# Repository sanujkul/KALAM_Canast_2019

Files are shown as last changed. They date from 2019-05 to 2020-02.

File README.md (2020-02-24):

# KALAM_Canast_2019    
These codes/files were written/developed for the Cansat competition 2019, USA.    

This folder have two types of files:  
1. Codes (.c, .c++, .ino)    
2. PCB designs    
  
Cansat 2019 was divided ino two parts: A payload and a container. Cansat is launched to the height of 750m and at the height of 450m, during descent journey,container would release the payload which will descent via auto-gyro mechanism.    
Cansat has to perform telemetry throughout its journey.   
  
Files descriptions:  
a. TeensyPayloadCodes : Have the Cansat's payload codes.   
b. Container_Final : Have the Cansat's container codes.    
c. Camera Stabilization Codes: Payload was divided into 2 subparts, minor subpart was camra stabilization system and these are codes for stabilizing the camera to shoot in a particular direction.   
d. Camera_Stabilisation_Tests: Codes written for testing Camera stabilization system.  
e. Bluetooth Tests: Camera stabilization setup used to communicate to main microcontroller (Teensy) via bluetooth and these are test codes for that.   
f. SumiranPCB: Contains PCB designs (Eagle Cad files) for the cansat.  
g. Packets: This is a class developed to use telemetry packet as an object to ease or work in organising the codeflow.

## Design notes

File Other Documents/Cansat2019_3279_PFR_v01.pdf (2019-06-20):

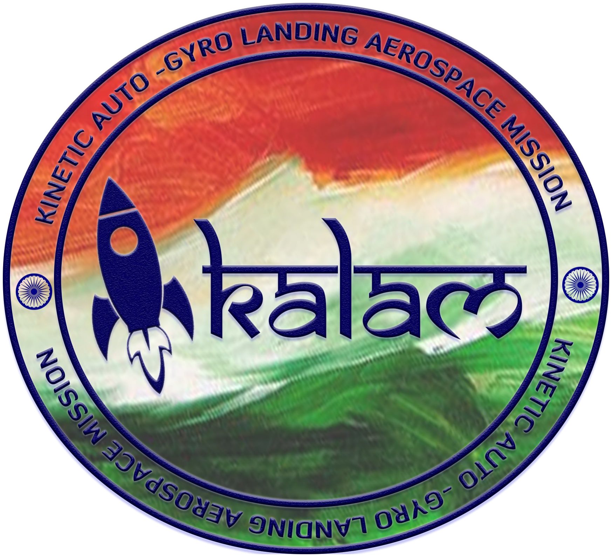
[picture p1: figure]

# Netaji Subhas University of Technology CanSat 2019 Post Flight Review (PFR)

#3279

K.A.L.A.M.

## Kinetic Autogyro Landing Aerospace Mission

CanSat 2019 PFR: Team 3279 (Team KALAM)

# Introduction

## ISHITA KOCHAR

CanSat 2019 PFR: Team 3279 (Team KALAM)

## Presentation Outline

S. no. | SECTION | PRESENTER | SLIDE NUMBER
1. | Introduction | Ishita Kochar | 2-4
2. | Systems Overview | Arham Jain | 5-11
3. Concept of operations and | sequence of events | Sumiran Bhasin | 12-19
4. | Flight data analysis | Vineet Khurana | 20-32
5. | Failure analysis | Sanuj Kulshrestha | 33-36
6. | Lessons learned | Anmol Gulati | 37-40
Presenter: Ishita Kochar | CanSat 2019 PFR: Team 3279 (Team KALAM)

## Team Organization

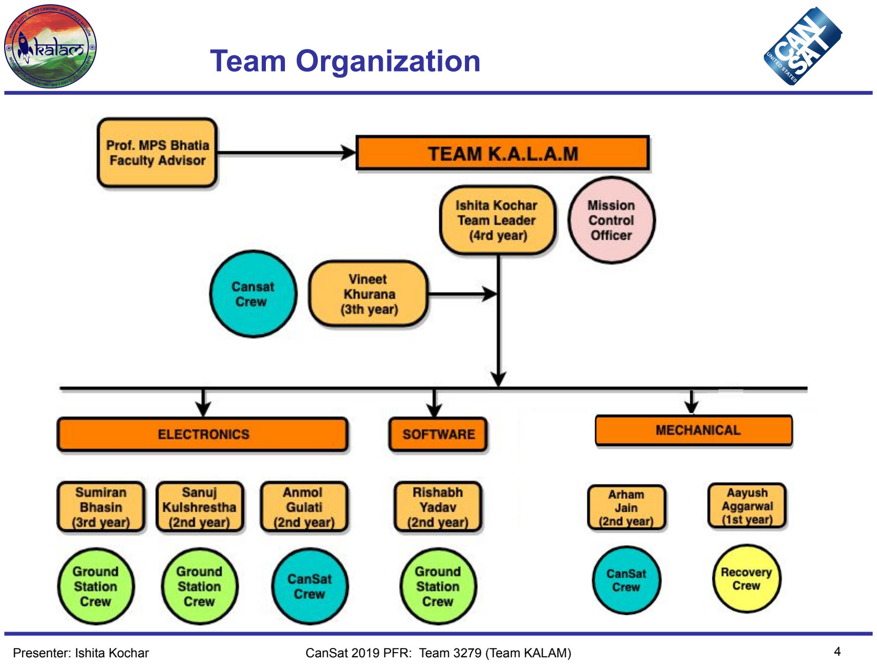
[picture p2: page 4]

Presenter: Ishita Kochar | CanSat 2019 PFR: Team 3279 (Team KALAM)

# Systems Overview

## ARHAM JAIN

CanSat 2019 PFR: Team 3279 (Team KALAM) | 5

## Payload Design Description

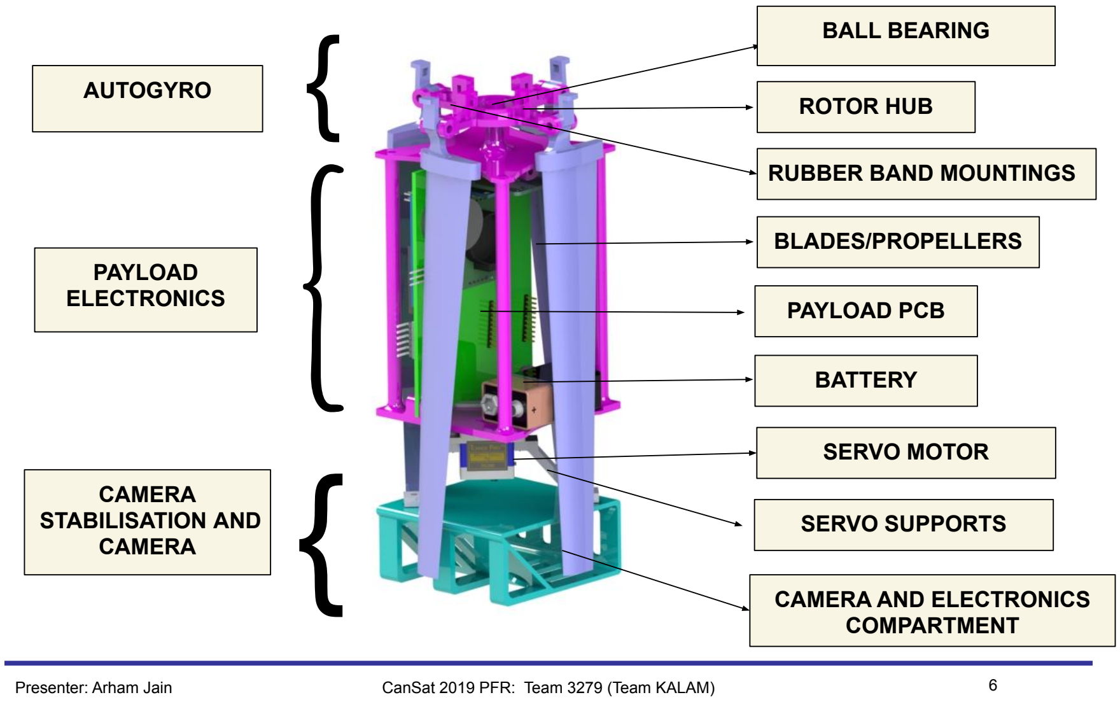
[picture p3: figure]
ROTOR HUB; BALL BEARING; BLADES/PROPELLERS; CAMERA AND ELECTRONICS COMPARTMENT; BATTERY; PAYLOAD PCB; SERVO MOTOR; SERVO SUPPORTS; RUBBER BAND MOUNTINGS; PAYLOAD ELECTRONICS; AUTOGYRO; CAMERA STABILISATION AND CAMERA; CanSat 2019 PFR: Team 3279 (Team KALAM); Presenter: Arham Jain

## Payload Design Description

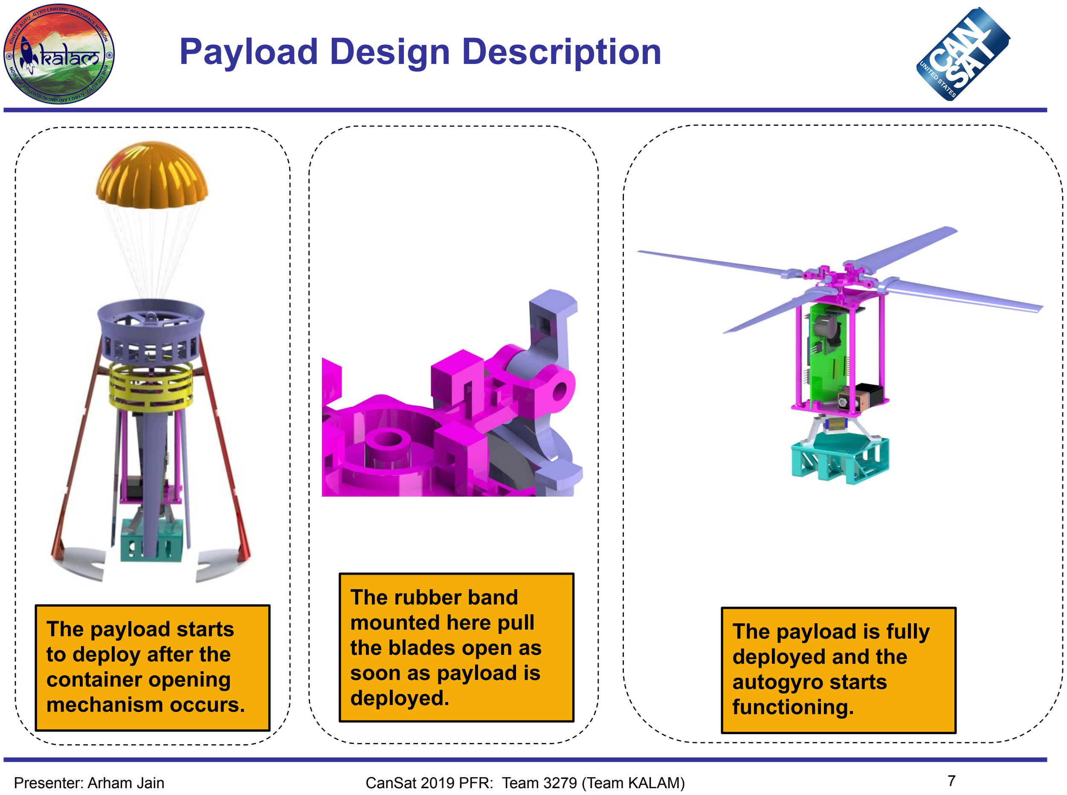
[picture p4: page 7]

Presenter: Arham Jain | CanSat 2019 PFR: Team 3279 (Team KALAM) | 7

The payload starts
to deploy after the
container opening
mechanism occurs.

The rubber band
mounted here pull
the blades open as
soon as payload is
deployed.

The payload is fully
deployed and the
autogyro starts
functioning.

## Payload Design Description

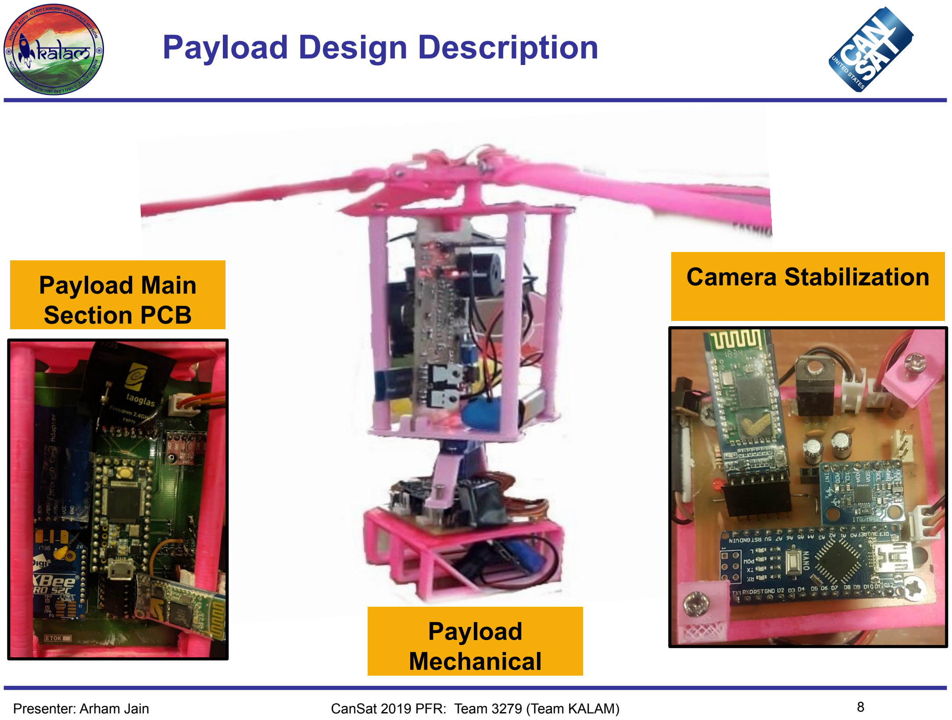
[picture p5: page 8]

Presenter: Arham Jain | CanSat 2019 PFR: Team 3279 (Team KALAM) | 8

Payload Main
Section PCB

Camera Stabilization

Payload
Mechanical

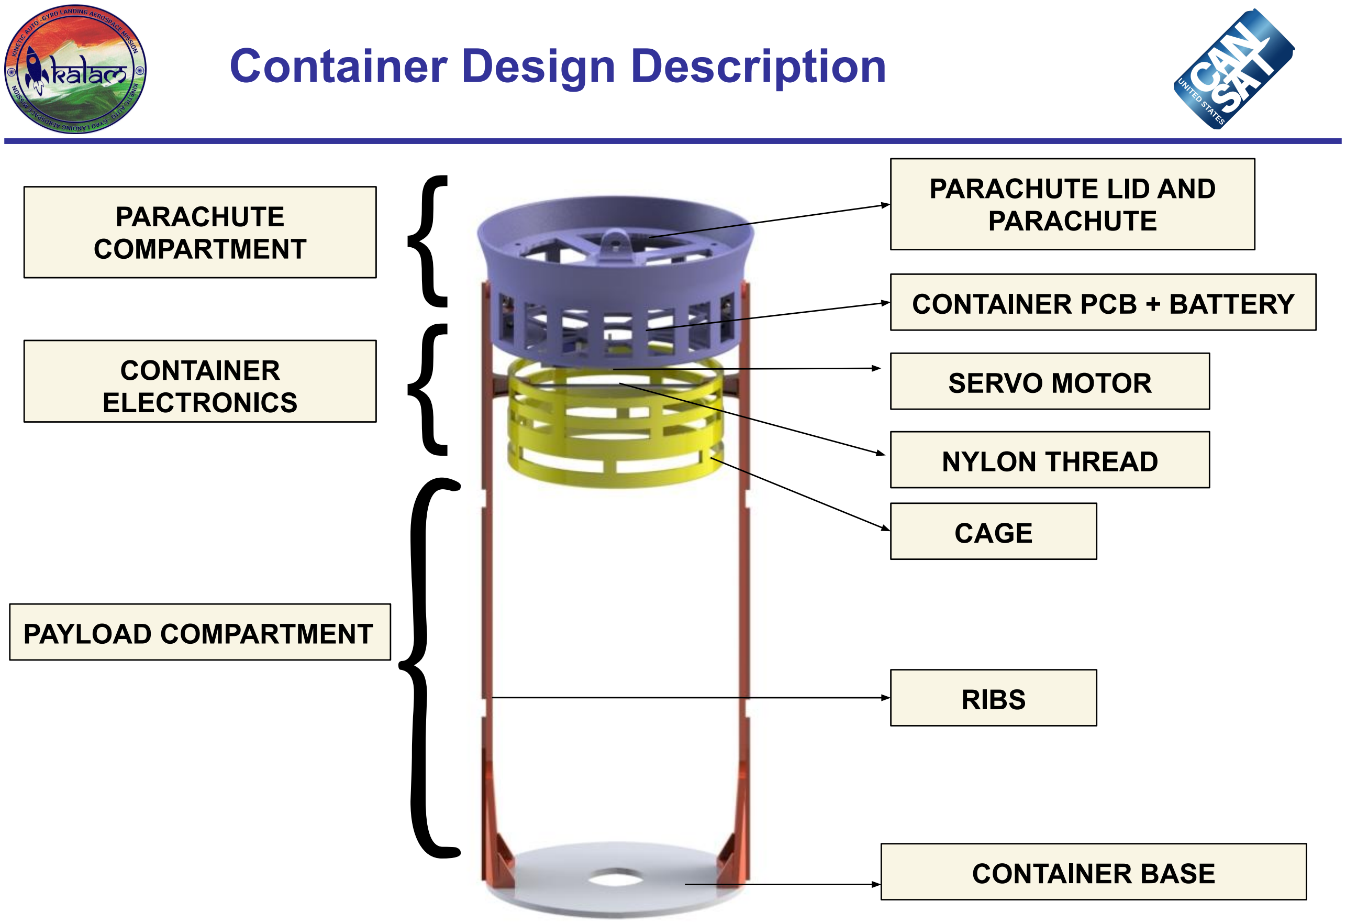
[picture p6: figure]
Container Design Description; CAGE; RIBS; CONTAINER PCB + BATTERY; SERVO MOTOR; CONTAINER BASE; NYLON THREAD; PARACHUTE COMPARTMENT; CONTAINER ELECTRONICS; PAYLOAD COMPARTMENT; PARACHUTE LID AND PARACHUTE

CanSat 2019 PFR: Team 3279 (Team KALAM) Presenter: Arham Jain

## Container Design Description

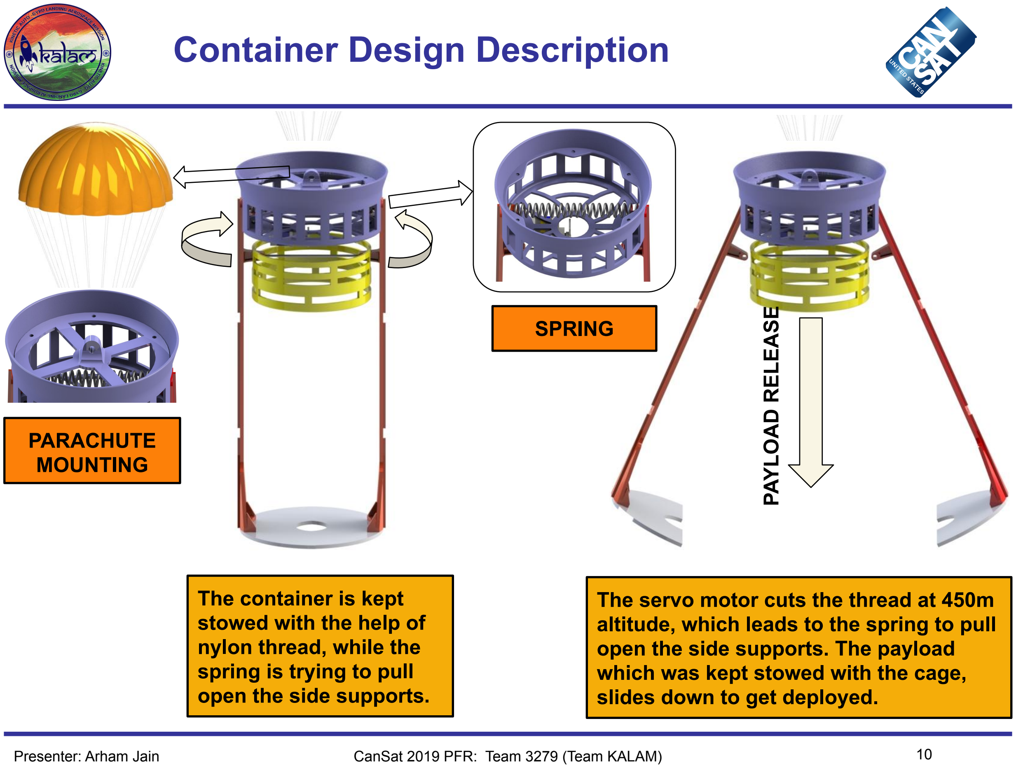
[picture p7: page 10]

CanSat 2019 PFR: Team 3279 (Team KALAM) | 10

The container is kept
stowed with the help of
nylon thread, while the
spring is trying to pull
open the side supports.

The servo motor cuts the thread at 450m altitude, which leads to the spring to pull open the side supports. The payload which was kept stowed with the cage, slides down to get deployed.

Presenter: Arham Jain

SPRING

PAYLOAD RELEASE

PARACHUTE
MOUNTING

## Container Design Description

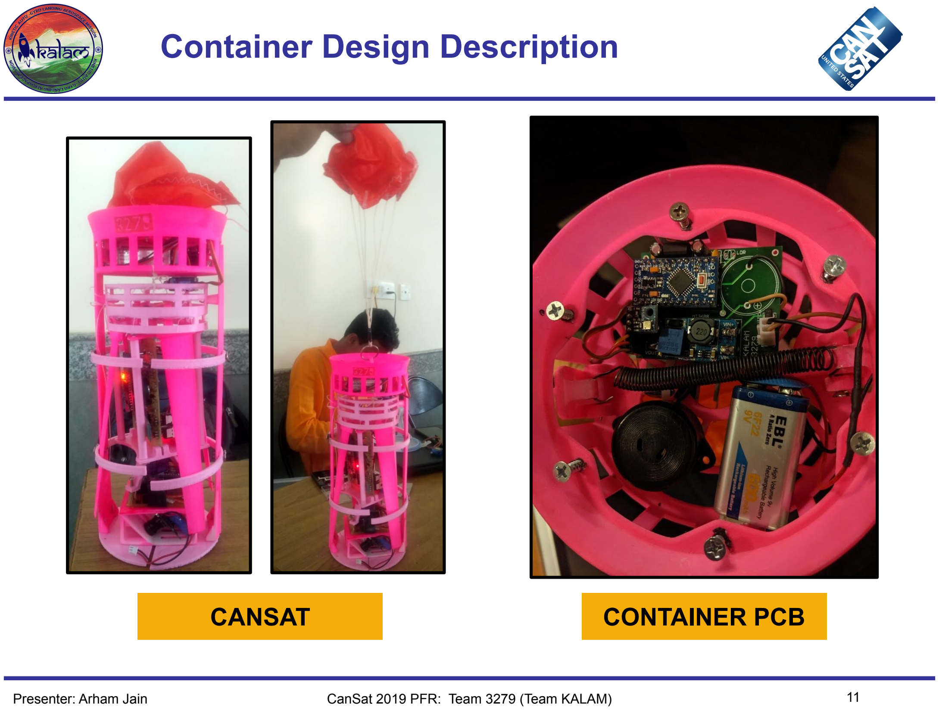
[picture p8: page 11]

Presenter: Arham Jain | CanSat 2019 PFR: Team 3279 (Team KALAM) | 11
CANSAT | CONTAINER PCB

# Concept of Operations and Sequence of Events

# Sumiran Bhasin

CanSat 2019 PFR: Team 3279 (Team KALAM)

## Comparison of planned and actual Con-Ops (1/2)

Presenter: Sumiran Bhasin

Planned Con-OPS | Actual Con-Ops | Team’s Remarks
- Payload integrity and Mechanical system integrity checks | Achieved | -
- Communication and GCS checks . | Achieved | -
- The software will be checked. | Achieved | -
- CanSat is switched ON, and telemetry starts. | Achieved | -
- CanSat integrated in the launch rocket. | Achieved | -
- CanSat released at apex at an altitude of around 700m. | Achieved | -
- Sensors start to collect data | Achieved | -
- The parachute of CanSat deploys right after the release. | Achieved | -
- The CanSat descents under parachute with velocity of 20 ± 5 m/s upto 450 m. | Partially Achieved | CanSat descents under parachute with velocity 14.7 m/s. (2% error from the prescribed lower limit)
- At the altitude of 450m, the servo motor cuts the nylon thread. | Partially Achieved | We expected servo cutting to take 1 second.

CanSat 2019 PFR: Team 3279 (Team KALAM)

## Comparison of planned and actual Con-Ops (2/2)

Planned Con-OPS | Actual Con-Ops | Teams’ Remarks
- The stretched/stressed spring gets compressed and pulls the container ribs open. | Achieved | -
- The stowed autogyro blades are deployed and start rotating. | Partially Achieved | Auto-gyro blades stuck with hall sensor that stopped its rotation.
- The payload descent under autogyro with velocity of 10m/s. | Partially Achieved | Payload descent with velocity of 13.75 m/s.
- The audio beacon on both container and payload starts after landing. | Not Achieved | -
- The telemetry transmission stops | Achieved | -
- The last GPS location of payload is used to narrow down the location. | Achieved | -
- The .csv file is copied to the thumb drive and handed over.. | Achieved | -
- PFR preparations are started. | Achieved | -
Presenter: Sumiran Bhasin | CanSat 2019 PFR: Team 3279 (Team KALAM)

## Comparison of planned and actual

## SOE (1/5)

## ARRIVAL

Planned SOE | Actual SOE
- Arrival on the launch site. | ● Arrived at 8 am
- Ground station is set up including antenna assembly and ground station settings. | ● Setup at the launch time around 2:05 pm
- Initial start-up of the program is done and GCS is configured. | ● Verified prior to the launch at 2:05 pm
- Communication with GCS is confirmed. | ● Verified prior to the launch at 2:05 pm

## 1.) ARRIVALS

Presenter: Sumiran Bhasin | CanSat 2019 PFR: Team 3279 (Team KALAM)

## Comparison of planned and actual

## SOE (2/5)

PRE-LAUNCH CHECKS

Planned SOE | Actual SOE
- All PCB connections are verified | ● All PCB connections are verified around 9:30 am
- Working of sensors and the triggers are verified | ● Working of sensors and the triggers are verified 10:00 am
- CanSat is checked for any physical damage. | ● CanSat is checked for any physical damage. 11:30 am
- Safety control | ● Safety control
- Weight check | ● It was done around 11:55 pm
- Environmental test have been successful | ● Environmental tests have been successful

## 2.) PRE-LAUNCH CHECKS

Presenter: Sumiran Bhasin | CanSat 2019 PFR: Team 3279 (Team KALAM)

## Comparison of planned and actual

## SOE (3/5)

## 3.) INTEGRATION AND LAUNCH

INTEGRATION AND LAUNCH

Planned SOE | Actual SOE
- Parachute is folded and placed into its designated compartment | ● Successfully folded and placed parachute in its designated compartment at 2:06 pm
- The payload is secured into the container | ● Verified securing of payload into the container at 2:06 pm
- The CanSat electronics are switched ON. | ● The CanSat electronics are switched ON at the launch time around 2:00 pm
- The CanSat assembly is fitted into the rocket. | ● The CanSat assembly is fitted into the rocket around 2:06 pm
- Launch | ● Launch successful at around 2:13 pm
Presenter: Sumiran Bhasin | CanSat 2019 PFR: Team 3279 (Team KALAM)

## Comparison of planned and actual

## SOE (4/5)

RECOVERY

Planned SOE | Actual SOE
- Container and payload are retrieved by the crew. | ● Container and payload are retrieved by the crew at 2:40pm
- The last GPS location of the payload helps to narrow down the area. | ● Thanks to the GPS coordinates
- The active audio beacon and bright pink color also aid in recovery. | ● Audio beacon didn’t work
- Both are inspected for any damage. | ● Container was found broken

## 4.) RECOVERY

Presenter: Sumiran Bhasin | CanSat 2019 PFR: Team 3279 (Team KALAM)

## Comparison of planned and actual

## SOE (5/5)

ANALYSIS AND PFR

Planned SOE | Actual SOE
- The payload and camera SD card are acquired. | ● Payload and camera section both recovered successfully.
- The received telemetry data and camera video are analyzed. | ● Telemetry data plotted and analysed , camera video was not recorded
- Delivery of received data to jury | ● Delivered successfully
- The data is utilized for mission assessment and PFR preparation. | ● Mission assessment done
- Delivery of the PFR file to the Jury. | ● Delivered

## 5.) ANALYSIS AND PFR

Presenter: Sumiran Bhasin | CanSat 2019 PFR: Team 3279 (Team KALAM)

# Flight Data Analysis

## VINEET KHURANA

CanSat 2019 PFR: Team 3279 (Team KALAM)

## Container Separation Altitude

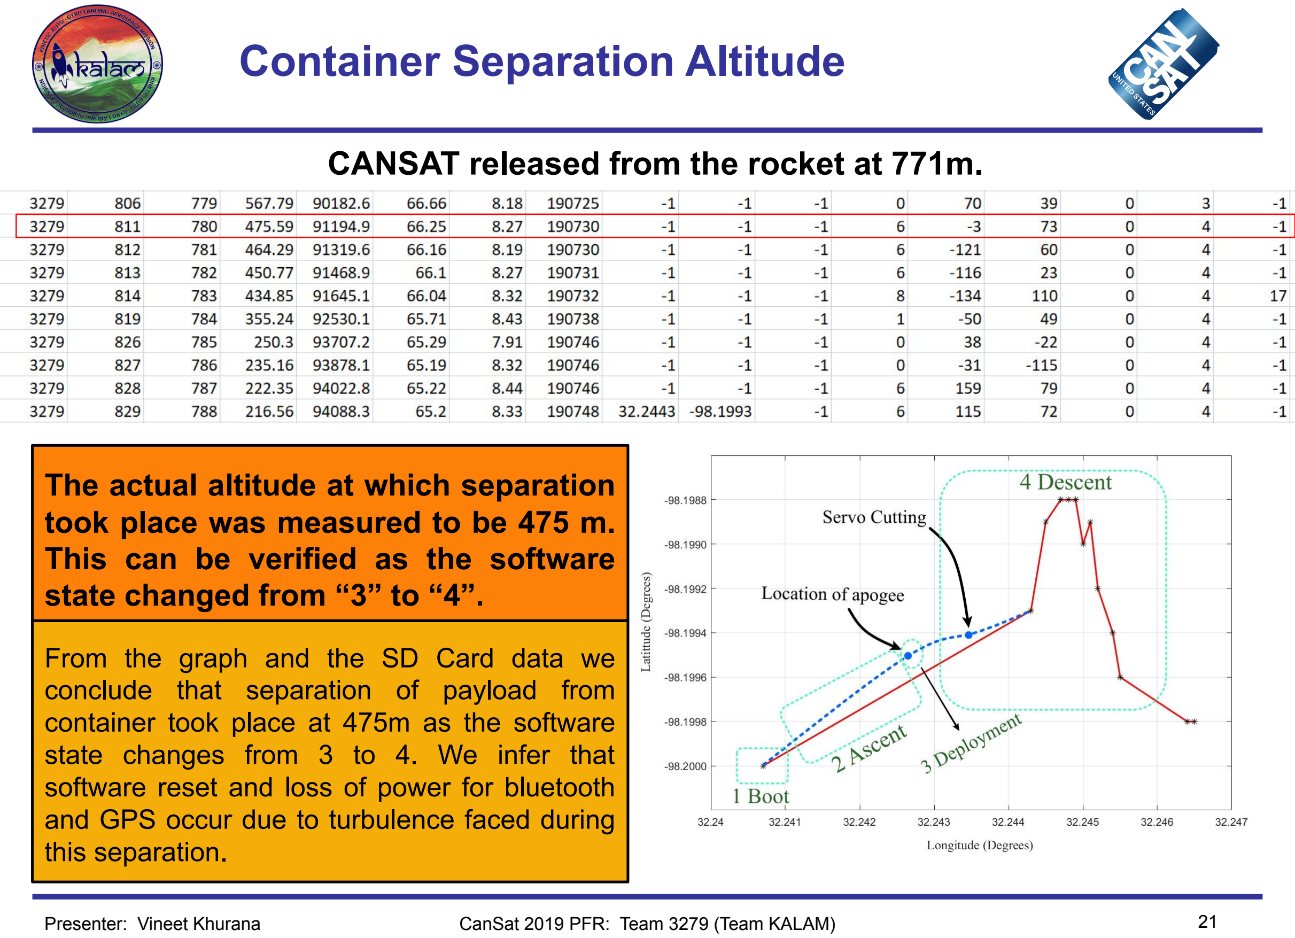
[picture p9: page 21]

Presenter: Vineet Khurana

CANSAT released from the rocket at 771m.

CanSat 2019 PFR: Team 3279 (Team KALAM)

From the graph and the SD Card data we conclude that separation of payload from container took place at 475m as the software state changes from 3 to 4. We infer that software reset and loss of power for bluetooth and GPS occur due to turbulence faced during this separation.

The actual altitude at which separation took place was measured to be 475 m. This can be verified as the software state changed from “3” to “4”.

## Payload pressure sensor data plot

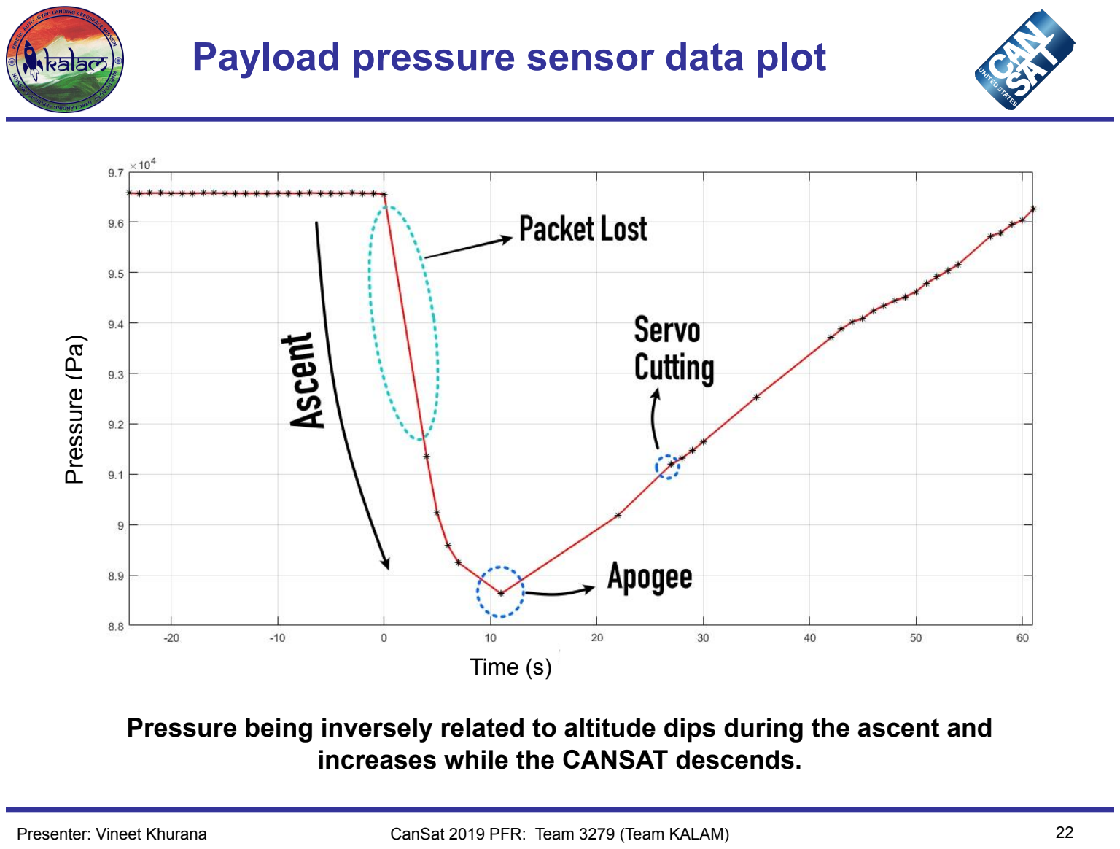
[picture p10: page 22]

CanSat 2019 PFR: Team 3279 (Team KALAM)

Pressure being inversely related to altitude dips during the ascent and increases while the CANSAT descends.

Presenter: Vineet Khurana | 22 Pressure ⁽Pa⁾

Time (s)

## Payload altitude plot

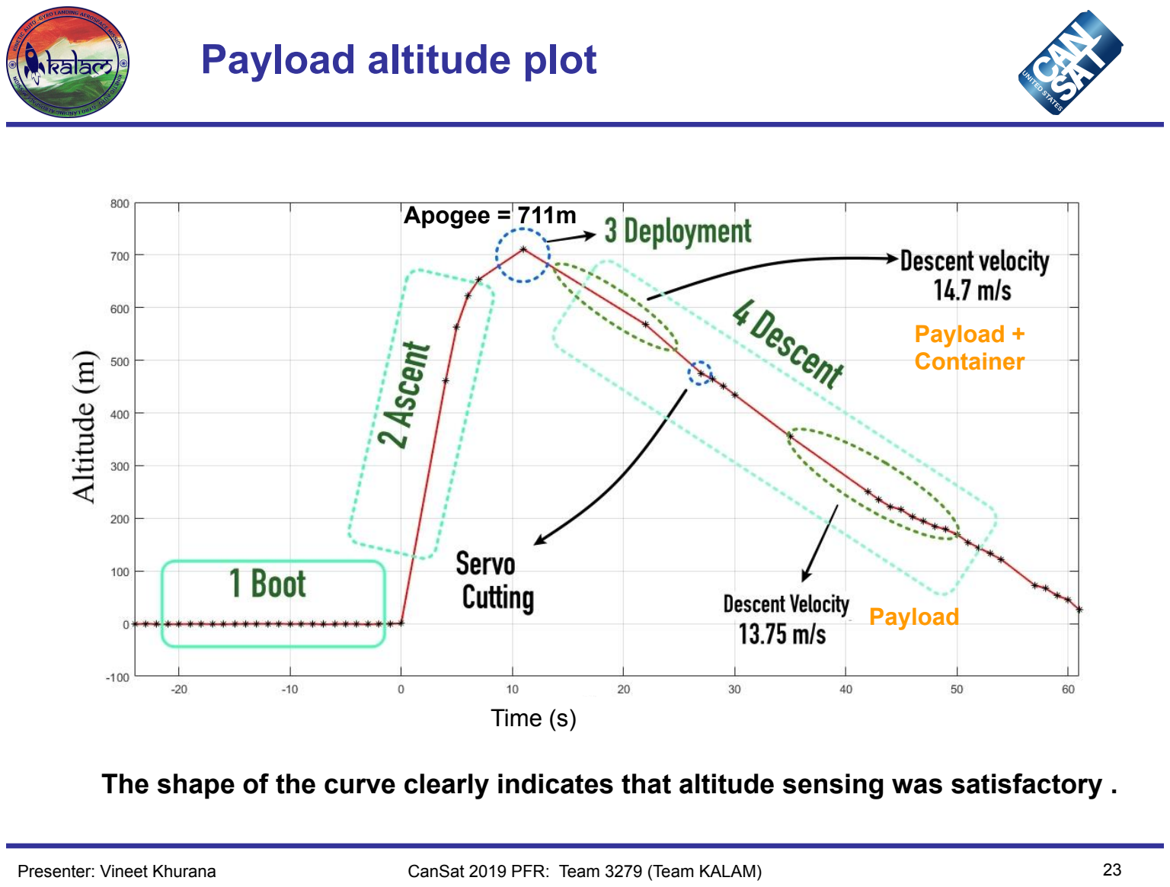
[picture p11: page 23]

Presenter: Vineet Khurana | CanSat 2019 PFR: Team 3279 (Team KALAM)

Apogee = 711m

Payload +
Container

Payload

The shape of the curve clearly indicates that altitude sensing was satisfactory .

Time (s)

## Payload temperature sensor plot

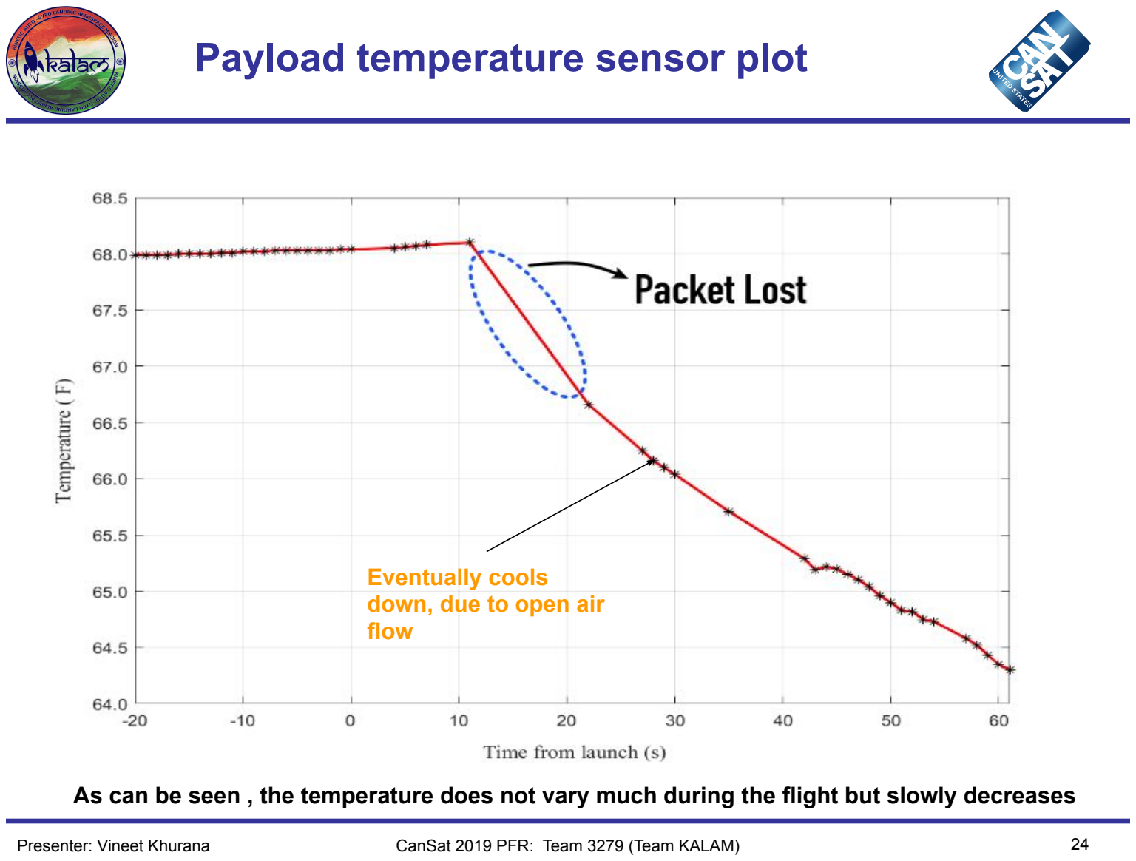
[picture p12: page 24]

Presenter: Vineet Khurana | CanSat 2019 PFR: Team 3279 (Team KALAM)

Eventually cools
down, due to open air
flow

As can be seen , the temperature does not vary much during the flight but slowly decreases

## Payload GPS plot (1/2)

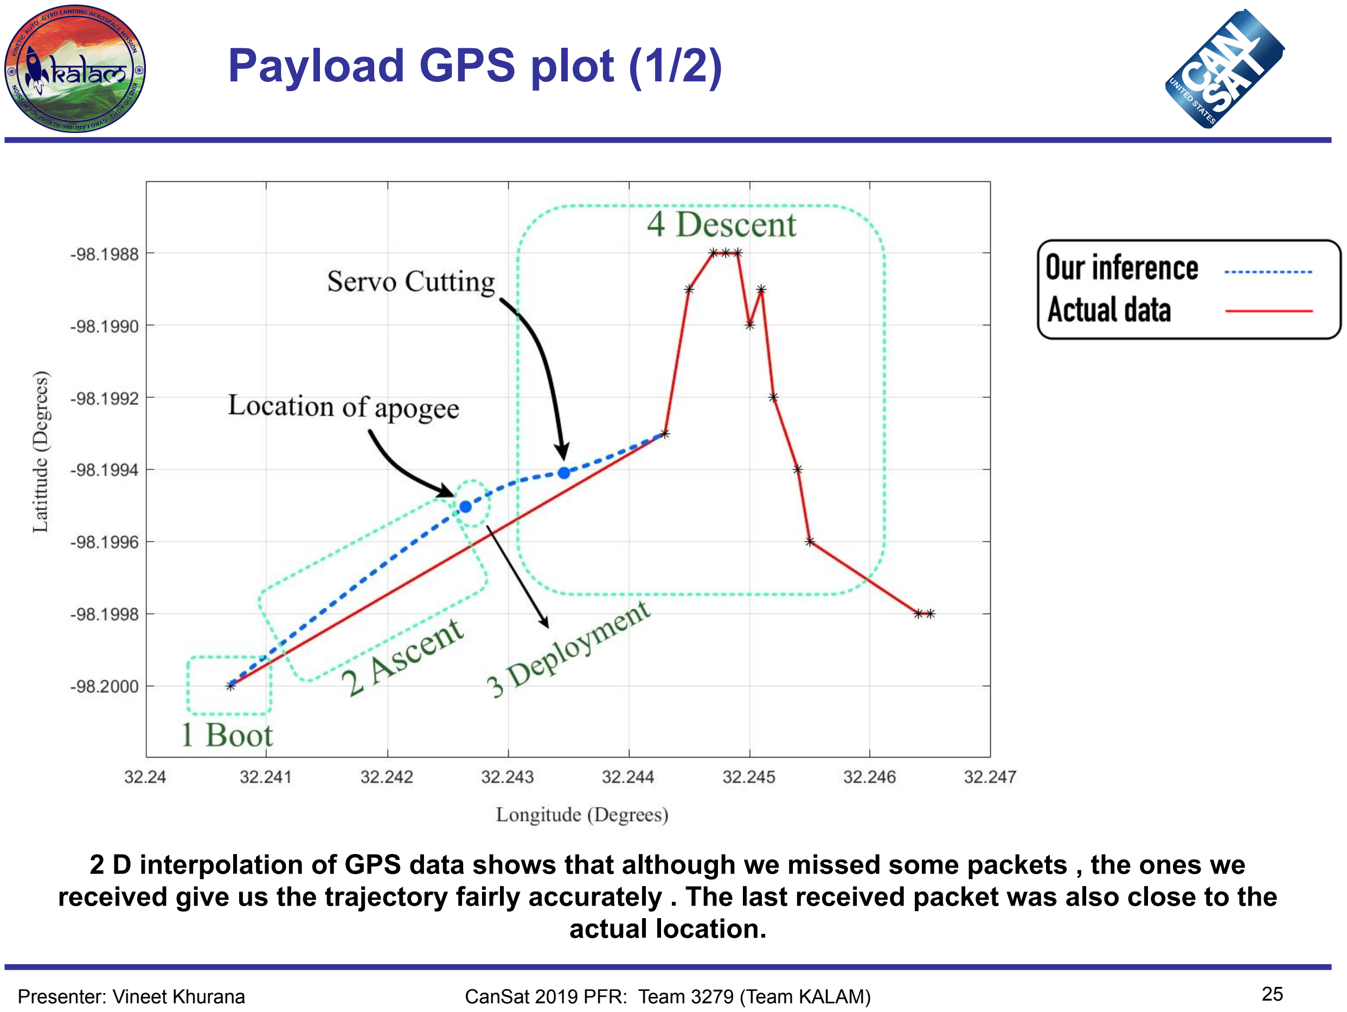
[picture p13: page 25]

Presenter: Vineet Khurana | CanSat 2019 PFR: Team 3279 (Team KALAM)

### 2 D interpolation of GPS data shows that although we missed some packets , the ones we

received give us the trajectory fairly accurately . The last received packet was also close to the actual location.

## Payload GPS plot (2/2)

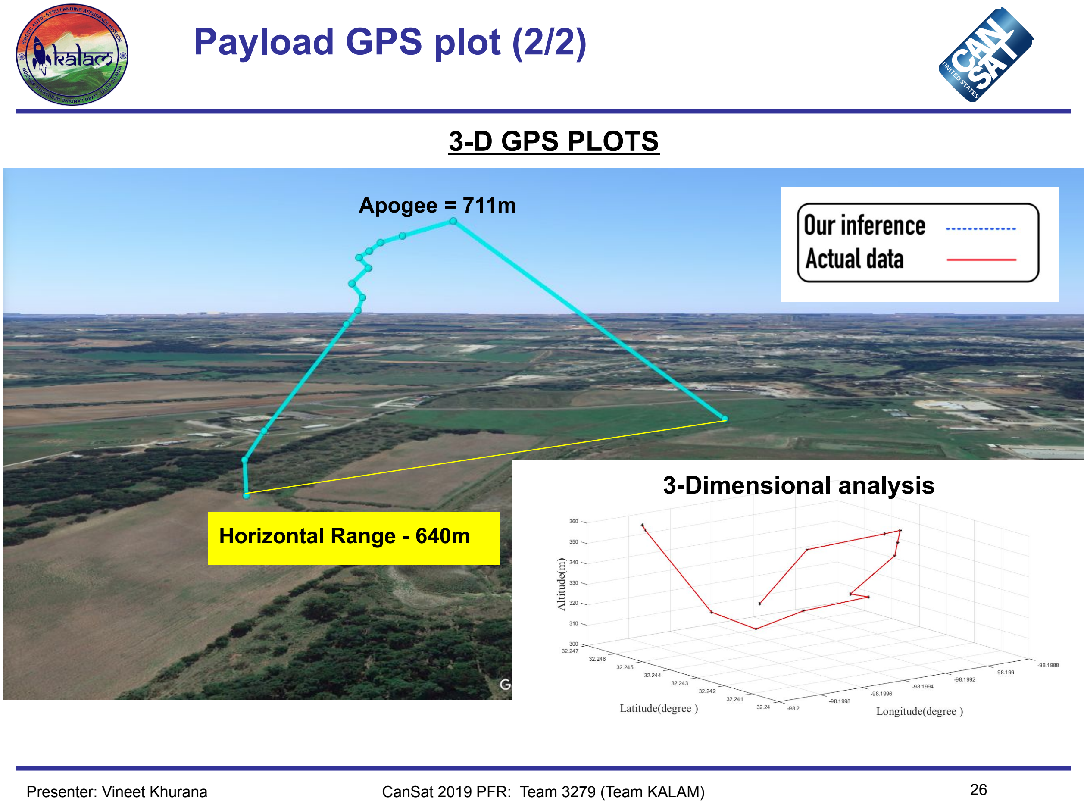
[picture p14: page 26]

Apogee = 711m

3-Dimensional analysis

3-D GPS PLOTS

Presenter: Vineet Khurana | CanSat 2019 PFR: Team 3279 (Team KALAM)

Horizontal Range - 640m

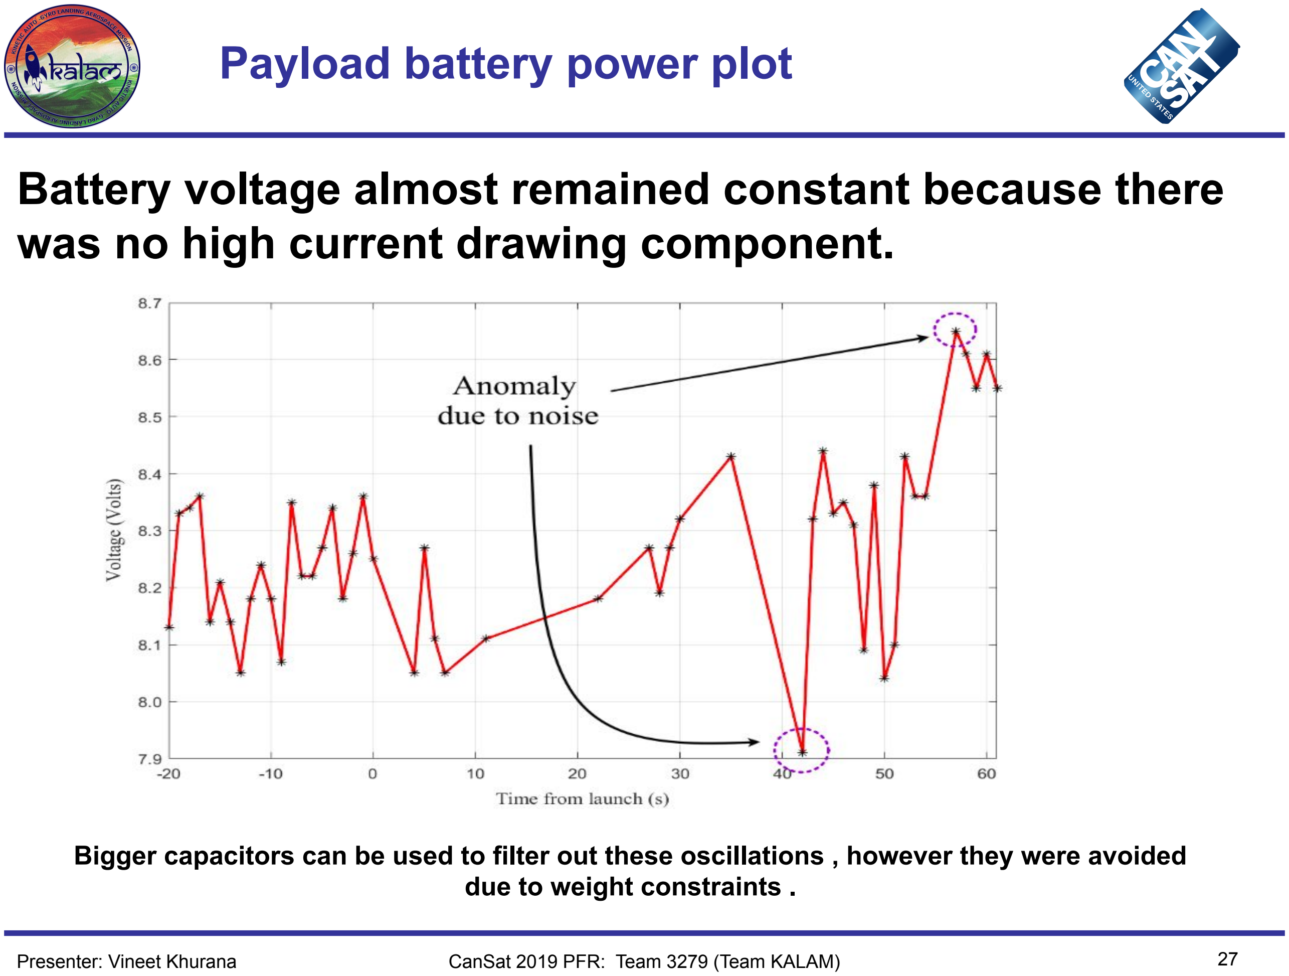
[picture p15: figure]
Payload battery power plot; was no high current drawing component.; due to weight constraints .

## Battery voltage almost remained constant because there

Presenter: Vineet Khurana | CanSat 2019 PFR: Team 3279 (Team KALAM)

Bigger capacitors can be used to filter out these oscillations , however they were avoided

## Tilt Sensor plot

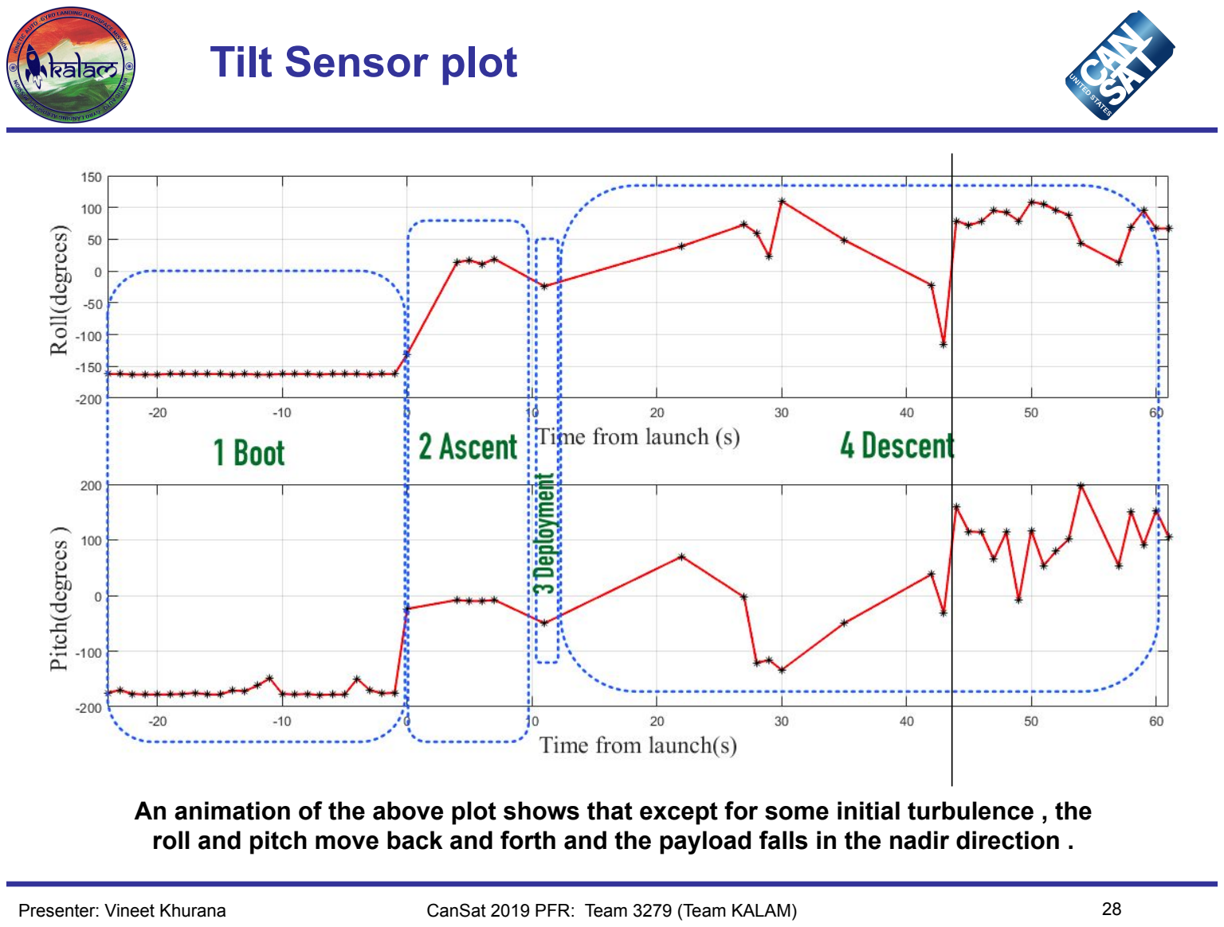
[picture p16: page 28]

Presenter: Vineet Khurana | CanSat 2019 PFR: Team 3279 (Team KALAM) | 28

An animation of the above plot shows that except for some initial turbulence , the roll and pitch move back and forth and the payload falls in the nadir direction .

## Auto-gyro blade spin rate plot

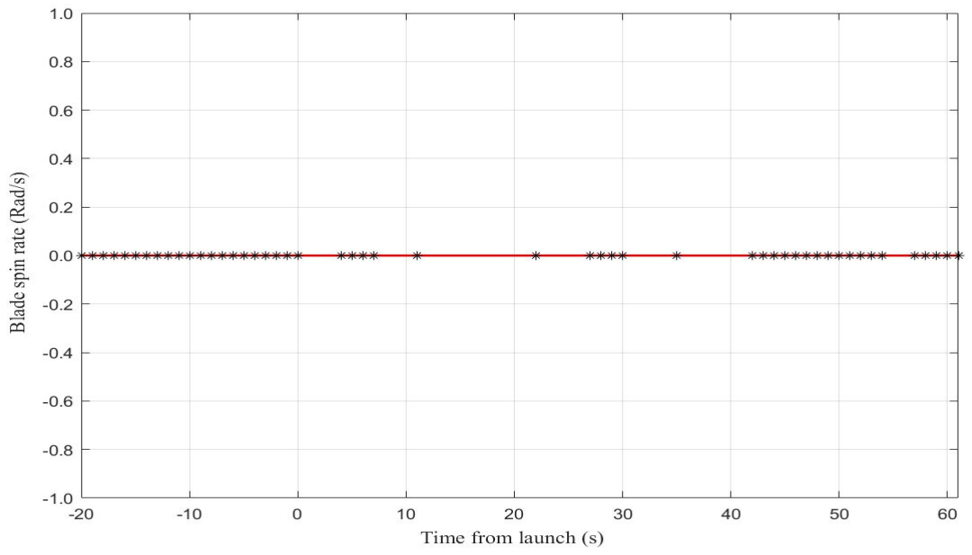
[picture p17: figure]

Presenter: Vineet Khurana | CanSat 2019 PFR: Team 3279 (Team KALAM)

Our Auto-Gyro blade spin is zero because one of the blade was stuck in container and its mounting then broke off and the rotation of rotor was also hindered by the loose wires of the hall sensor.

## Camera Video (1/3)

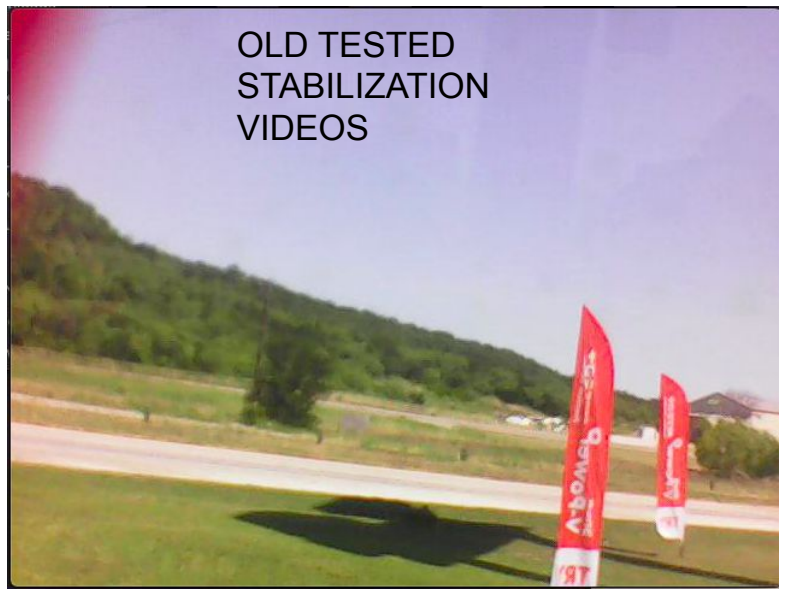
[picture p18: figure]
STABILIZATION VIDEOS
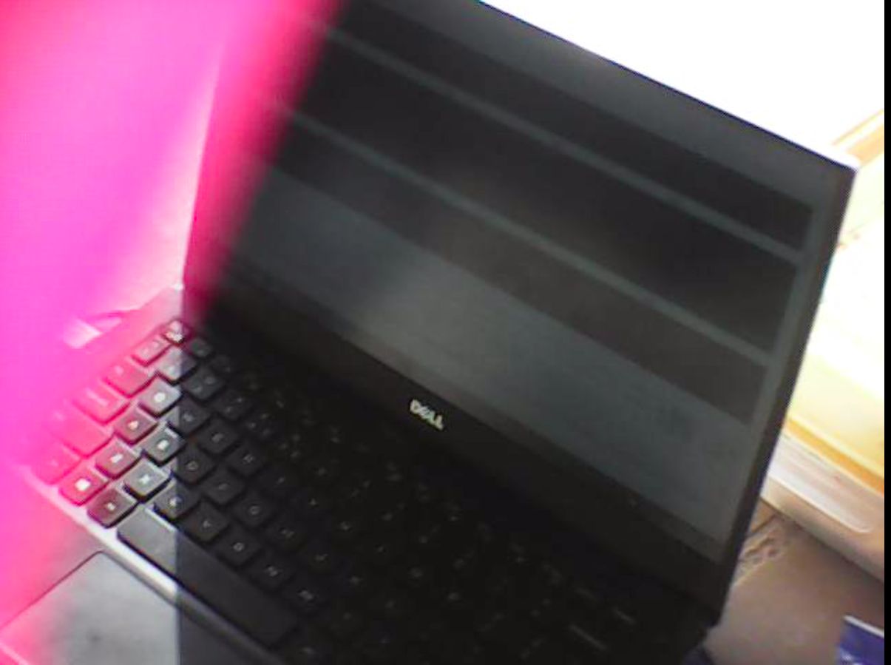
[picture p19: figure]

Presenter: Vineet Khurana | CanSat 2019 PFR: Team 3279 (Team KALAM) | 30

This was unexpected because camera stabilization system worked well and camera SD Card recorded video too during testing (images on left) and that’s why we invested 130g weight (Current weight = 628) more by developing stabilization system in the cansat.

After the flight we found the wire that switches on/off the camera was broken. Reasons could be the jerks faced during take off or deployment.

Our camera didn’t record anything in the SD card during flight though our stabilization system worked.

OLD TESTED | BONUS PARTIALLY ACHIEVED

## Camera Video (2/3)

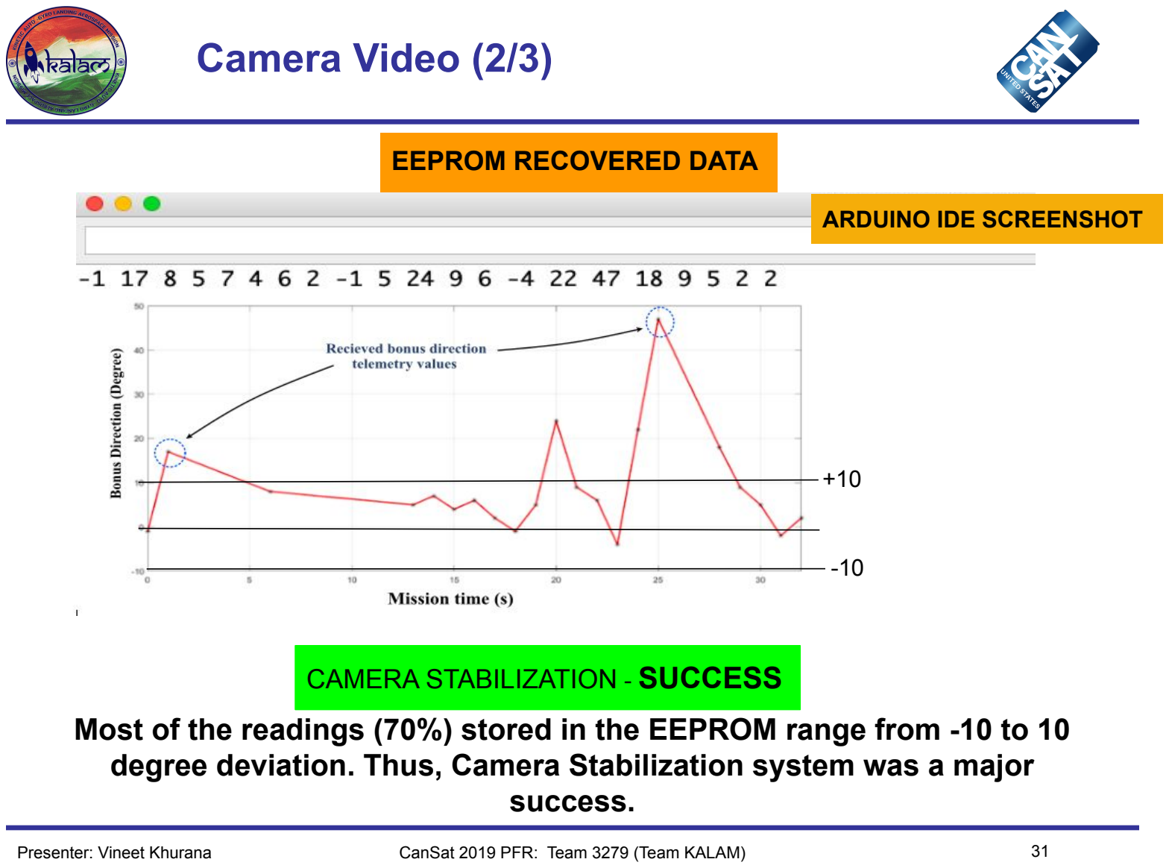
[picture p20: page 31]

Presenter: Vineet Khurana | CanSat 2019 PFR: Team 3279 (Team KALAM) | 31

EEPROM RECOVERED DATA

CAMERA STABILIZATION - SUCCESS

Most of the readings (70%) stored in the EEPROM range from -10 to 10 degree deviation. Thus, Camera Stabilization system was a major success.

ARDUINO IDE SCREENSHOT

+10

-10

## Camera Video (3/3)

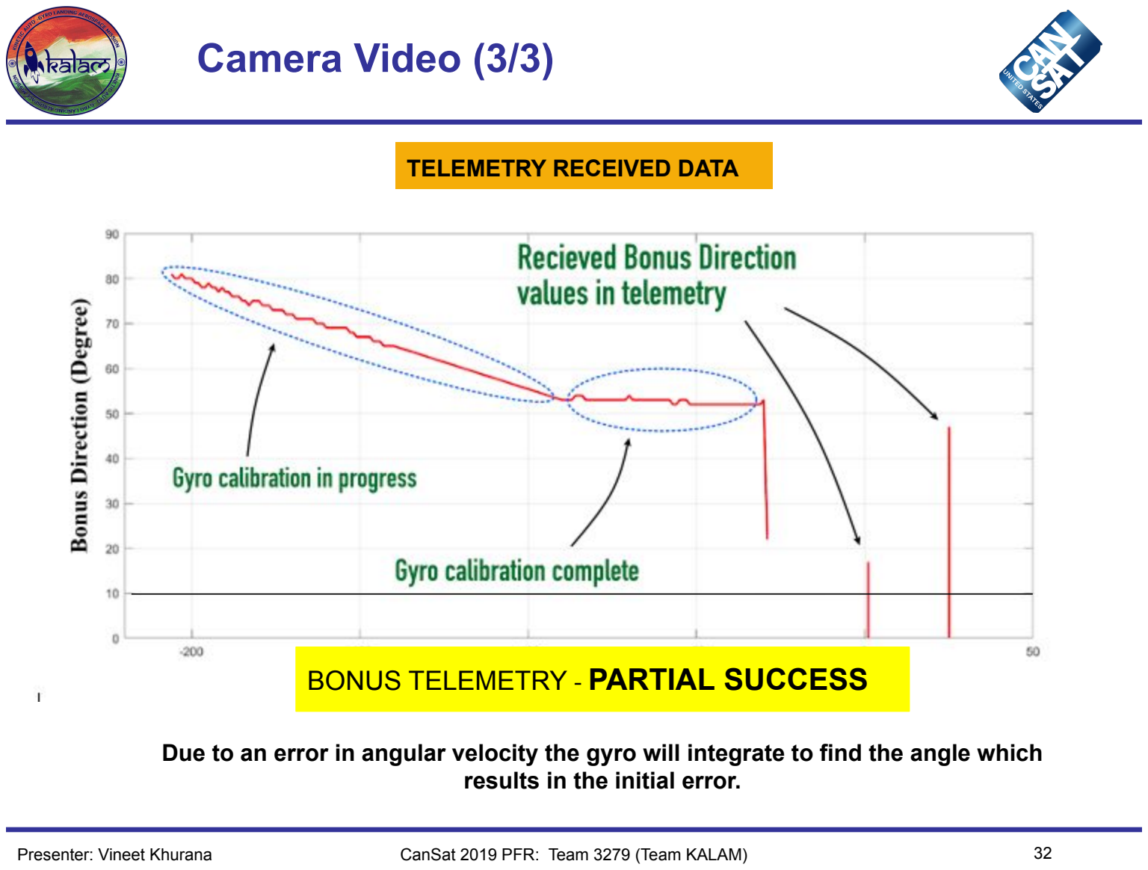
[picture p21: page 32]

Presenter: Vineet Khurana | CanSat 2019 PFR: Team 3279 (Team KALAM) | 32

TELEMETRY RECEIVED DATA

Due to an error in angular velocity the gyro will integrate to find the angle which results in the initial error.

BONUS TELEMETRY - PARTIAL SUCCESS

# Failure Analysis

## SANUJ KULSHRESTHA

CanSat 2019 PFR: Team 3279 (Team KALAM)

CanSat 2019 PFR: Team 3279 (Team KALAM) | 34

## Identification of failures, root causes, corrective actions (1/3)

Failure | Root cause | Corrective action
Audio Beacon failure | Payload must have hit the ground and damaged the system before it could change to END state. As data sample rate is 1 Hz and and last stored altitude is 26m. | Better software alternative could’ve been designed for this problem and auto-gyro would have reduced the speed for current software to work
Failure of storing of Bonus video in SD Card | The camera switch on/off wire broke off and nothing was saved in the SD Card | Using firm headers to tighten the connection
CanSat weighed more than 500 grams | With an aim to complete the bonus objective , the entire camera subsystem’s electronics and mechanical model were different and modular which caused an extra weight of about 130 gms | Entire payload could have one single battery reducing the weight and the mechanical model could have lost some of the weight.

Presenter: Sanuj Kulshrestha

## Identification of failures, root causes, corrective actions (2/3)

Failure | Root cause | Corrective action
Blade stuck | Our spring was not stiff enough and it hence one of the payload blades struck in the container rib and one mounting broke off. | A better spring with stiffer spring constant could be used.
Container broken | The material wasn’t sturdy enough and it struck the ground from its side supports | A better material could have been used such as carbon fibre but was avoided due to cost reasons.
Auto gyro failure | Because one of the blades was stuck in container and the mounting broke off , the payload fell off from the container leaving the blade above . The rotation of rotor was also hindered by the loose wires of the hall sensor. | More secure mounting of hall sensor and
Presenter: Sanuj Kulshrestha | CanSat 2019 PFR: Team 3279 (Team KALAM)

## Identification of failures, root causes, corrective actions (3/3)

Failure | Root cause | Corrective action
Received 496 packets. 87 Packets not received out of 583 | For some time during launch, deployment and descent, due to power cut off ,teensy faced software reset due to which packets were not generated and transmitted | Better hardware connections and mounting of electronics may not have created this problem
Presenter: Sanuj Kulshrestha | CanSat 2019 PFR: Team 3279 (Team KALAM)

# Lessons Learned

## ANMOL GULATI

CanSat 2019 PFR: Team 3279 (Team KALAM)

## Discussion of what worked and what didn't (1/2)

## WHAT WORKED

Payload electronics and software worked successfully as expected.

Servo cutting mechanism worked.

Successful telemetry of 496 samples were received at a frequency of 1 Hz during the mission time of 549 seconds, thereby achieving a 87% success rate.

GPS coordinates were used to recover the payload.

Camera stabilization worked and the bonus direction was also telemetry to the ground station (partial).

Presenter: Anmol Gulati | CanSat 2019 PFR: Team 3279 (Team KALAM)

## WHAT DID NOT WORK

The total mass of the CanSat was 628g. Bonus Camera Stabilization system increased the weight by 130g. A single battery could’ve been used in the payload system instead of heavy multiple batteries presently used.

The audio beacon could not turn on in the last 5m as the last recorded altitude by the sensor is 26m.

The container was found broken after the recovery.

Failure of bluetooth communication between upper payload and camera stabilization system at the deployment time failed us to store camera recording.

Auto-Gyro blades rotation was interfered by the placement of hall sensor and also one of the blade mounting broke because it was stuck in container.

## Discussion of what worked and what didn't (2/2)

Presenter: Anmol Gulati | CanSat 2019 PFR: Team 3279 (Team KALAM)

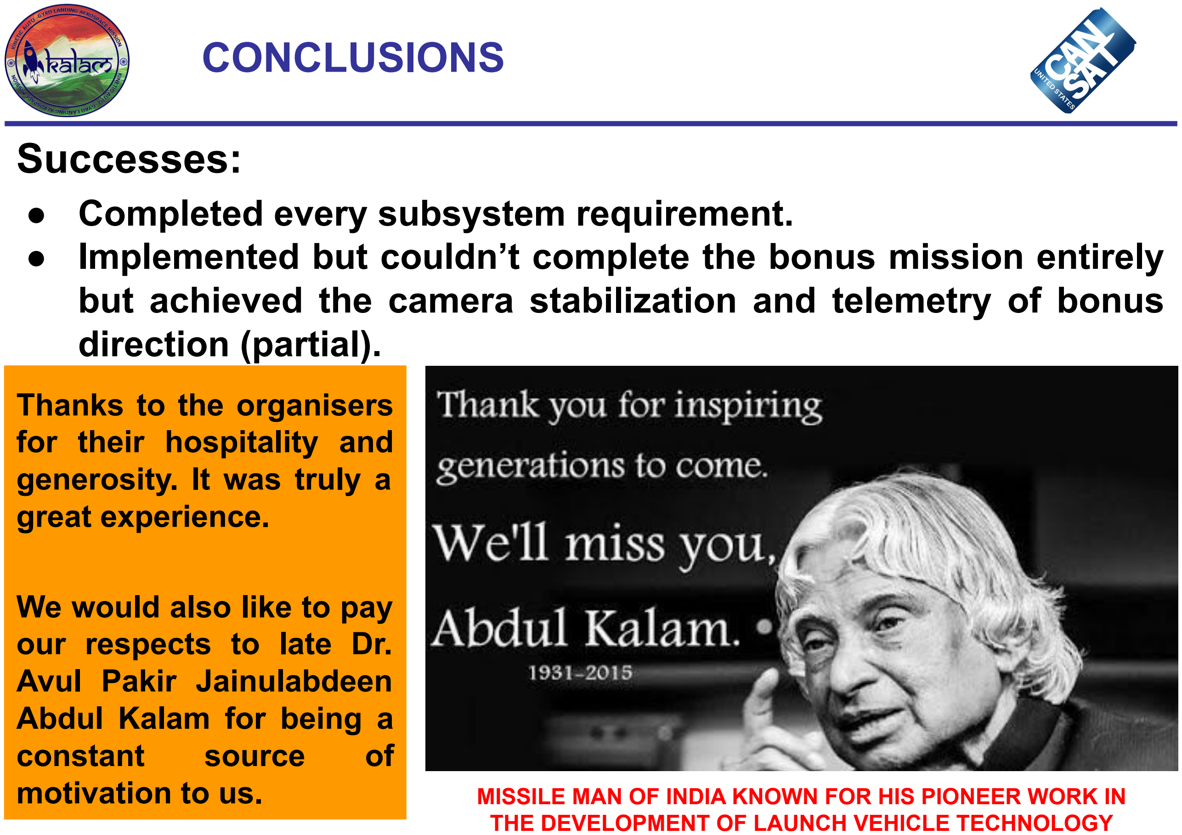
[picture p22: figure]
CONCLUSIONS; Successes:; direction (partial).; Thanks to the organisers for their hospitality and generosity. It was truly a great experience.; We would also like to pay our respects to late Dr. Avul Pakir Jainulabdeen Abdul Kalam for being a; constant; source

- Completed every subsystem requirement.
- Implemented but couldn’t complete the bonus mission entirely but achieved the camera stabilization and telemetry of bonus
Presenter: Anmol Gulati | CanSat 2019 PFR: Team 3279 (Team KALAM) | 40
motivation to us. | MISSILE MAN OF INDIA KNOWN FOR HIS PIONEER WORK IN
| THE DEVELOPMENT OF LAUNCH VEHICLE TECHNOLOGY

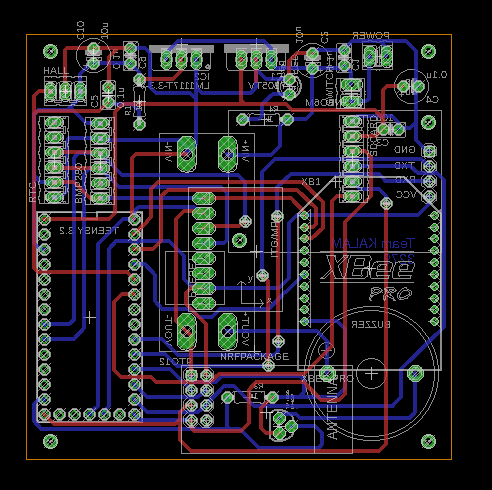
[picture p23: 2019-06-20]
SumiranPCB/SumiranPCB4/boardlayout.png

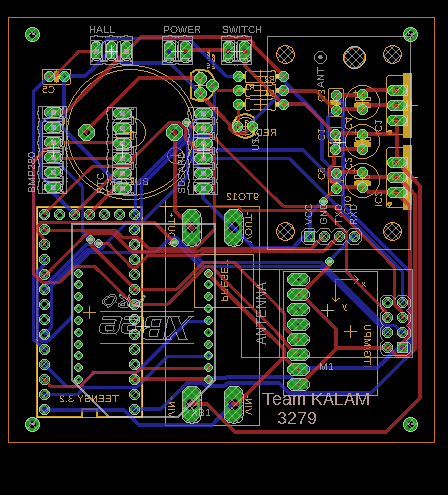
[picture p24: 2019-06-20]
SumiranPCB/Final PCBs/finalboard.png

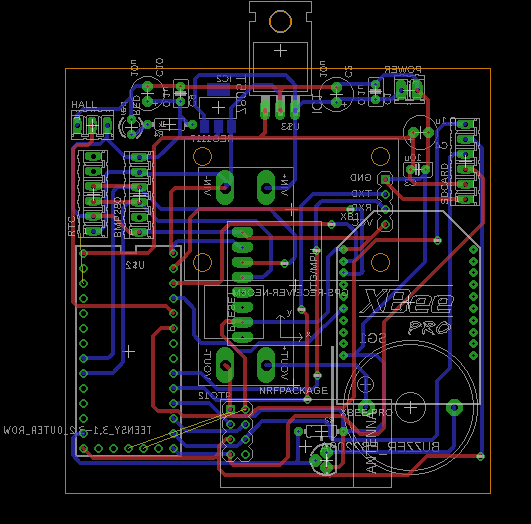
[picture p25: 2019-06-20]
SumiranPCB/Eagle_Sumiran2/boardlayout.png

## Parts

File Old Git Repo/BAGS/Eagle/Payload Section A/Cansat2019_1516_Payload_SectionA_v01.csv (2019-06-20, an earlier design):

Part | Value | Device | Package
BAT1 |  | BATTERY20PTH | BATTCOM_20MM_PTH
BAT_CON |  | M02 | 02P
BMP280 |  | M06 | 06P
C1 | 10u | CPOL-EUE2.5-6 | E2
C2 | 10u | CPOL-EUE2.5-6 | E2
C3 | 0.1u | C-EU025-025X050 | C025-025X050
C4 | 0.1u | C-EU025-025X050 | C025-025X050
COIN |  | JUMPER-2PTH | 1X02
D1 | 1N5819 | 1N5819 | DO41-10
D2 | 1N5819 | 1N5819 | DO41-10
HALL |  | M03 | 03P
IC1 | LM1117-3.3V-SOT223 | LM1117-3.3V-SOT223 | SOT223
IC2 | OPAMP-DUALDIP | OPAMP-DUALDIP | DIP08
LDR |  | M02 | 02P
M1 | WIRELESS-NRF24L01 | WIRELESS-NRF24L01 | WIRELESS-NRF24L01
MPU_ADD |  | JUMPER-2PTH | 1X02
MT3608 | MT3608_BOB | MT3608_BOB | MT3608_BOB
PWR | M04X2 | M04X2 | 2X4
PWR_LED |  | LED3MM | LED3MM
Q1 | MOSFET-NCHANNEL2N7000 | MOSFET-NCHANNEL2N7000 | TO-92
R1 | 10k | R-EU_0204/7 | 0204/7
R2 | 1k | R-EU_0204/7 | 0204/7
R4 | 10k | R-EU_0204/7 | 0204/7
R5 | 10k | R-EU_0204/7 | 0204/7
R6 | 10k | R-EU_0204/7 | 0204/7
SD |  | M06 | 06P
SG1 | F/CM04P | F/CM04P | F/CM04P
SWITCH |  | M02 | 02P
U$1 |  | SAM_D21_MINI_BREAKOUT | JP1_SPARKFUN-SAMD21-MINI-BREAKOUT-V10
U$2 | PRESET_LR | PRESET_LR | PRESET_LR
U$3 | GPS-RECEIVER-NEO6M | GPS-RECEIVER-NEO6M | GPS-RECEIVER-NEO6M
U1 | GY-521MPU6050 | GY-521MPU6050 | GY-521
XB1 | XBEE-PRO | XBEE-PRO | XBEE-PRO

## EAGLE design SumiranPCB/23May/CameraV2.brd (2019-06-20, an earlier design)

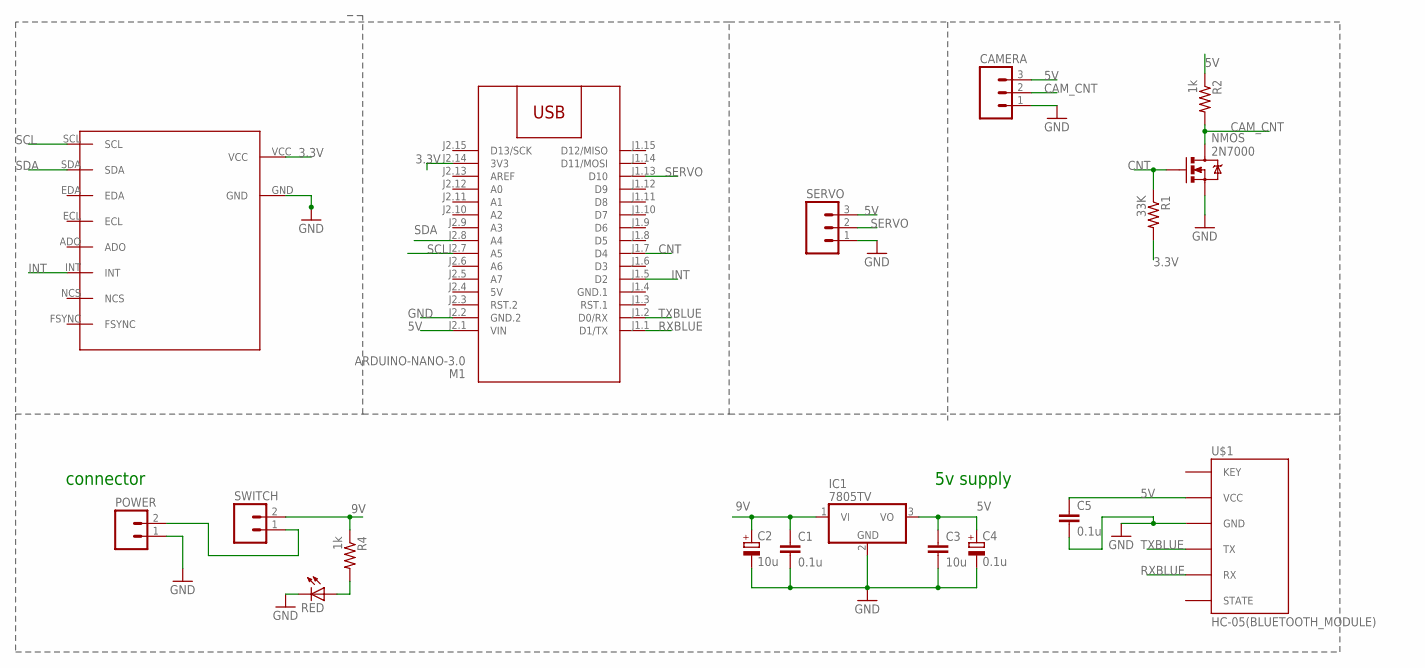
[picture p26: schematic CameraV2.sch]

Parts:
C1, C5: 0.1u; C025-025X050
C2: 10u; E2,5-6
C3: 10u; C025-025X050
C4: 0.1u; E2,5-6
CAMERA: CON-AMP-QUICK_M03; CON-AMP-QUICK_03P
IC1: 7805TV; TO220V
M1: ARDUINO-NANO-3.0
POWER: CEDT_JANUARY_2015_V5_M02; CEDT_JANUARY_2015_V5_02P
Q1: SPARKFUN-DISCRETESEMI_MOSFET-NCHANNEL2N7000; SPARKFUN-DISCRETESEMI_TO-92
R1: 33K; 0204/7
R2, R4: 1k; 0204/7
RED: red; LED3MM
SERVO: CON-AMP-QUICK_M03; CON-AMP-QUICK_03P
SWITCH: M02; 02P
U$1: HC-05(BLUETOOTH_MODULE); HC-05
U$2: MPU9250

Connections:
3.3V: M1.J2.14 (3V3), R1.2, U$2.VCC
5V: C3.1, C4.+, C5.1, CAMERA.3, IC1.3 (VO), M1.J2.1 (VIN), M1.J2.4 (5V), R2.1, SERVO.3, U$1.VCC
9V: C1.1, C2.+, IC1.1 (VI), R4.1, SWITCH.2
CAM_CNT: CAMERA.2, Q1.3 (D), R2.2
CNT: M1.J1.7 (D4), Q1.2 (G), R1.1
GND: C1.2, C2.-, C3.2, C4.-, C5.2, CAMERA.1, IC1.2 (GND), M1.J2.2 (GND.2), POWER.1, Q1.1 (S), RED.K (C), SERVO.1, U$1.GND, U$2.GND
GND.1: M1.J1.4 (GND.1)
INT: M1.J1.5 (D2), U$2.INT
unnamed: POWER.2, SWITCH.1
unnamed: R4.2, RED.A
RXBLUE: M1.J1.1 (D1/TX), U$1.RX
SCL: M1.J2.7 (A5), U$2.SCL
SDA: M1.J2.8 (A4), U$2.SDA
SERVO: M1.J1.13 (D10), SERVO.2
TXBLUE: M1.J1.2 (D0/RX), U$1.TX

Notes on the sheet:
connector
5v supply

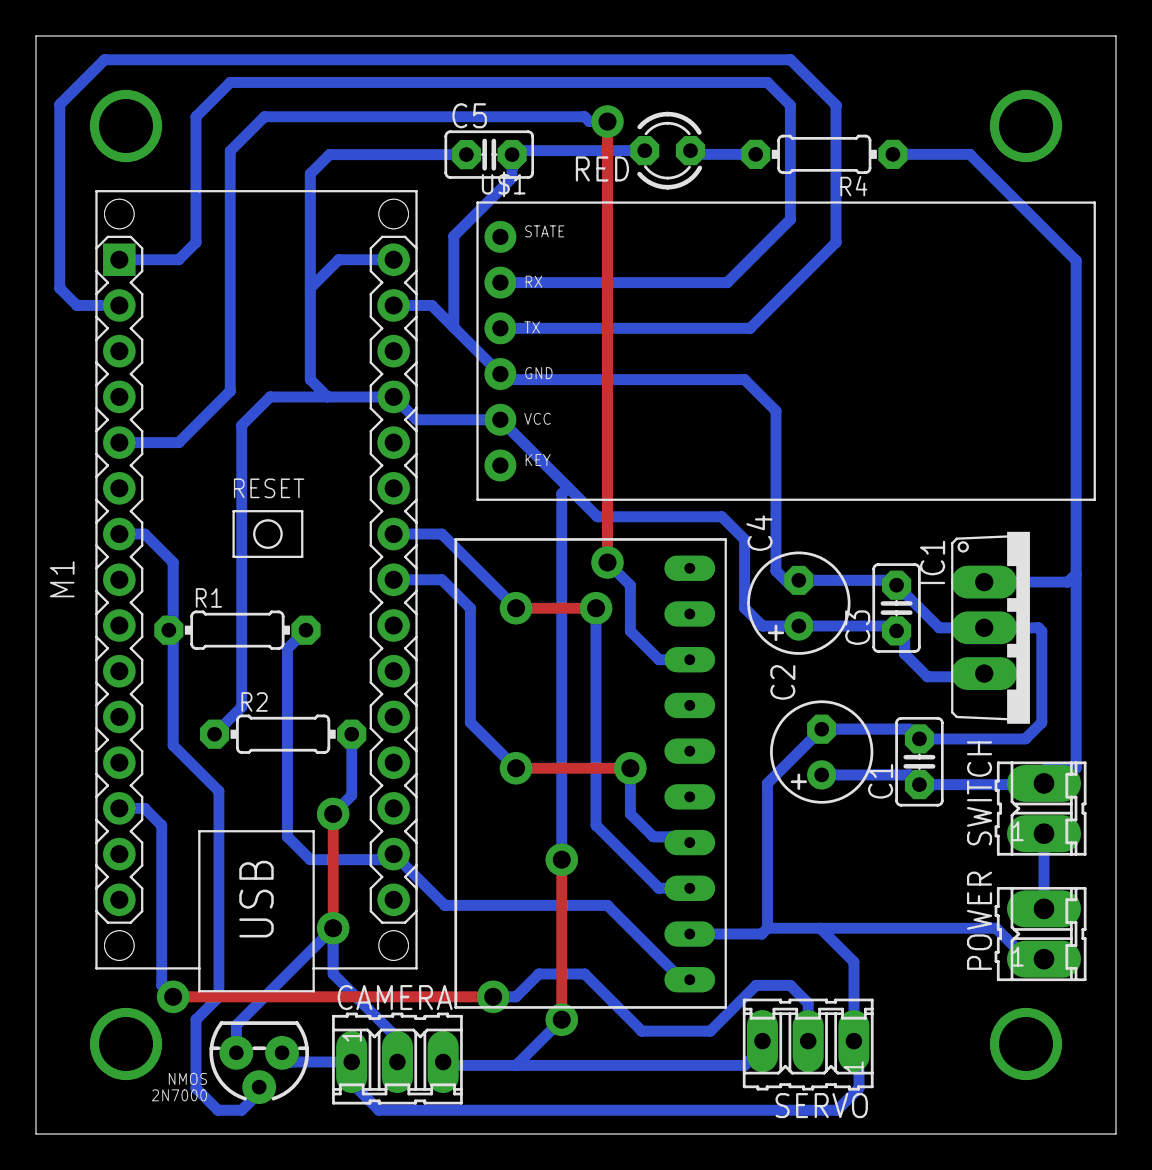
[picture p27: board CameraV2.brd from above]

Board: 2 copper layers, 60.0 x 61.0 mm, 18 parts (0 on the bottom side), 14 nets.

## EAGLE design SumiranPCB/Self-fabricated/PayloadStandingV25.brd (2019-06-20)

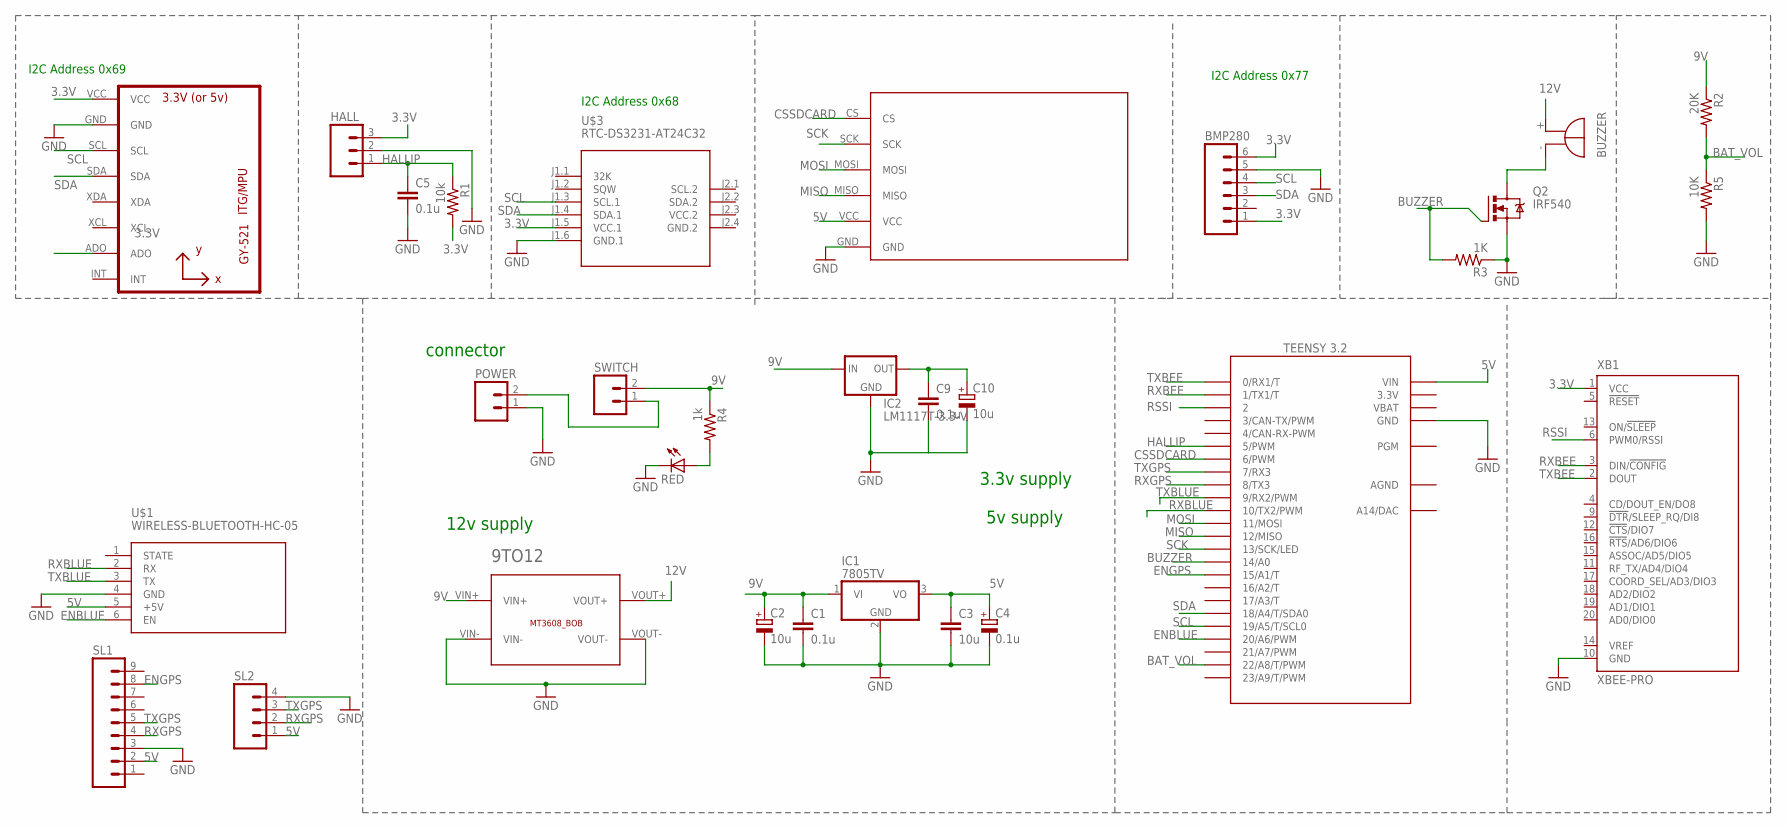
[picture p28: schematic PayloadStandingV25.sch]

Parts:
9TO12: BREAKOUTS_MT3608_BOB
BMP280: M06; 06P
C1, C5, C9: 0.1u; C025-025X050
C2, C10: 10u; E2,5-6
C3: 10u; C025-025X050
C4: 0.1u; E2,5-6
HALL: M03; 03P
IC1: 7805TV; TO220V
IC2: LM1117T-3.3-V; TO220V
POWER: CEDT_JANUARY_2015_V5_M02; CEDT_JANUARY_2015_V5_02P
Q2: IRF540; TO220BV
R1: 10k; 0204/7
R2: 20K; 0204/7
R3: 1K; 0204/7
R4: 1k; 0204/7
R5: 10K; 0204/7
RED: red; LED3MM
SG1: BUZZER_EB2209A
SL1: M09; 09P
SL2: CON-AMP-QUICK_M04; CON-AMP-QUICK_04P
SWITCH: M02; 02P
U1: GY-521MPU6050; GY-521
U$1: WIRELESS-BLUETOOTH-HC-05
U$2: TEENSY_3.1-3.2_OUTER_ROW; TEENSY_3.0-3.2&LC_OUTER_ROW
U$3: RTC-DS3231-AT24C32
U$5: SDCARD; M0SDCARDMODULE
XB1: XBEE-PRO

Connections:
3.3V: BMP280.1, BMP280.6, C9.1, C10.+, HALL.3, IC2.2 (OUT), R1.2, U1.ADO, U1.VCC, U$2.3.3V, U$2.3.3V1 (3.3V), U$3.J1.5 (VCC.1), XB1.1 (VCC)
5V: C3.1, C4.+, IC1.3 (VO), SL1.2, SL2.1, U$1.5 (+5V), U$2.VIN, U$5.VCC
9V: 9TO12.VIN+, C1.1, C2.+, IC1.1 (VI), IC2.3 (IN), R2.1, R4.1, SWITCH.2
12V: 9TO12.VOUT+, SG1.+
AGND: U$2.AGND
BAT_VOL: R2.2, R5.1, U$2.22/A8 (22/A8/T/PWM)
BUZZER: Q2.G, R3.2, U$2.14/A0
CSSDCARD: U$2.6 (6/PWM), U$5.CS
ENBLUE: U$1.6 (EN), U$2.20/A6 (20/A6/PWM)
ENGPS: SL1.8, U$2.15/A1 (15/A1/T)
GND: 9TO12.VIN-, 9TO12.VOUT-, BMP280.5, C1.2, C2.-, C3.2, C4.-, C5.2, C9.2, C10.-, HALL.2, IC1.2 (GND), IC2.1 (GND), POWER.1, Q2.S, R3.1, R5.2, RED.K (C), SL1.3, SL2.4, U1.GND, U$1.4 (GND), U$2.GND, U$2.GND1 (GND), U$3.J1.6 (GND.1), U$5.GND, XB1.10 (GND)
GND.2: U$3.J2.4 (GND.2)
HALLIP: C5.1, HALL.1, R1.1, U$2.5 (5/PWM)
MISO: U$2.12 (12/MISO), U$5.MISO
MOSI: U$2.11 (11/MOSI), U$5.MOSI
unnamed: POWER.2, SWITCH.1
unnamed: R4.2, RED.A
unnamed: Q2.D, SG1.-
RSSI: U$2.2, XB1.6 (PWM0/RSSI)
RXBEE: U$2.1 (1/TX1/T), XB1.3 (DIN/!CONFIG)
RXBLUE: U$1.2 (RX), U$2.10 (10/TX2/PWM)
RXGPS: SL1.4, SL2.2, U$2.8 (8/TX3)
SCK: U$2.13 (13/SCK/LED), U$5.SCK
SCL: BMP280.4, U1.SCL, U$2.19/A5 (19/A5/T/SCL0), U$3.J1.3 (SCL.1)
SDA: BMP280.3, U1.SDA, U$2.18/A4 (18/A4/T/SDA0), U$3.J1.4 (SDA.1)
TXBEE: U$2.0 (0/RX1/T), XB1.2 (DOUT)
TXBLUE: U$1.3 (TX), U$2.9 (9/RX2/PWM)
TXGPS: SL1.5, SL2.3, U$2.7 (7/RX3)
VBAT: U$2.VBAT
VCC.2: U$3.J2.3 (VCC.2)

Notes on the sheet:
connector
3.3v supply
5v supply
12v supply
I2C Address 0x77
I2C Address 0x68
I2C Address 0x69

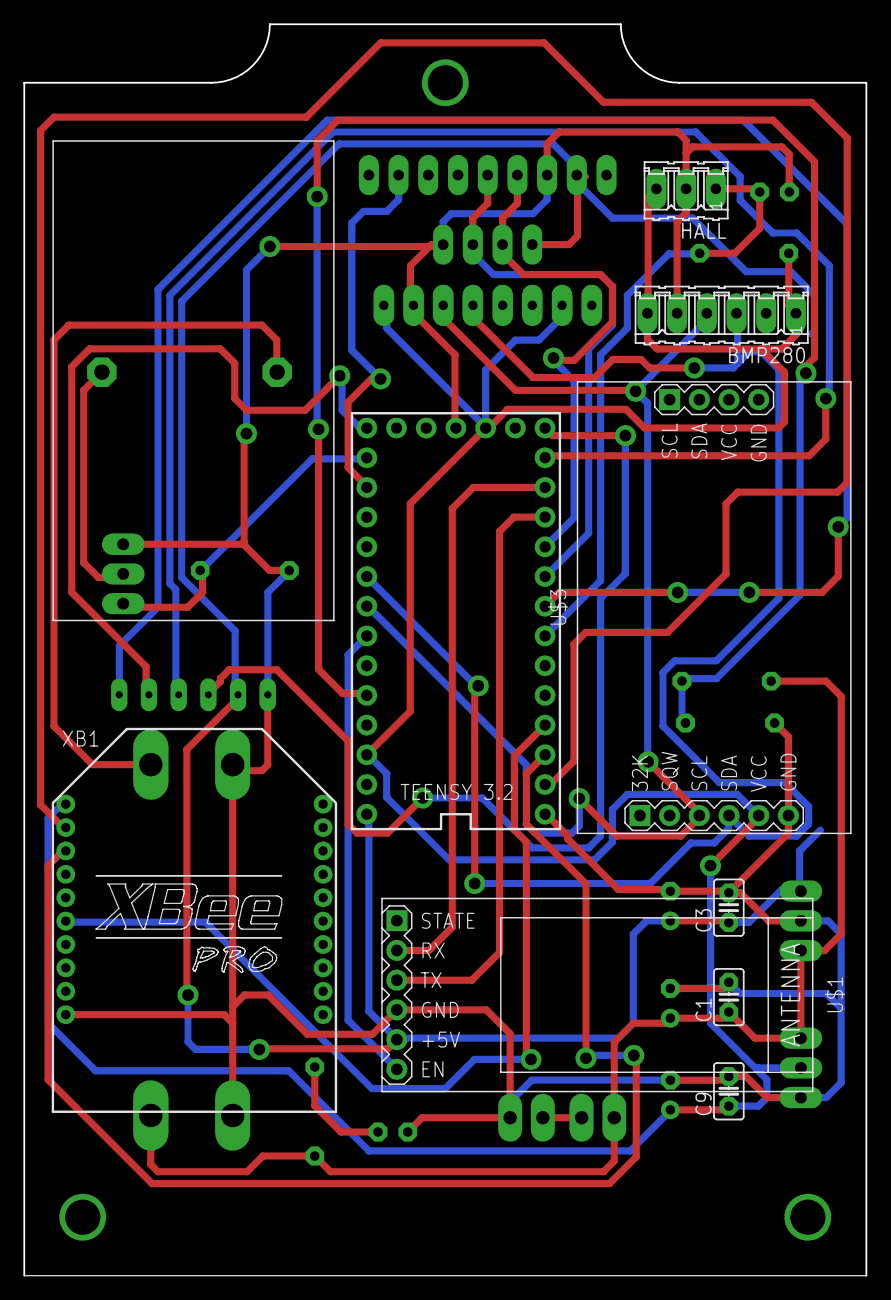
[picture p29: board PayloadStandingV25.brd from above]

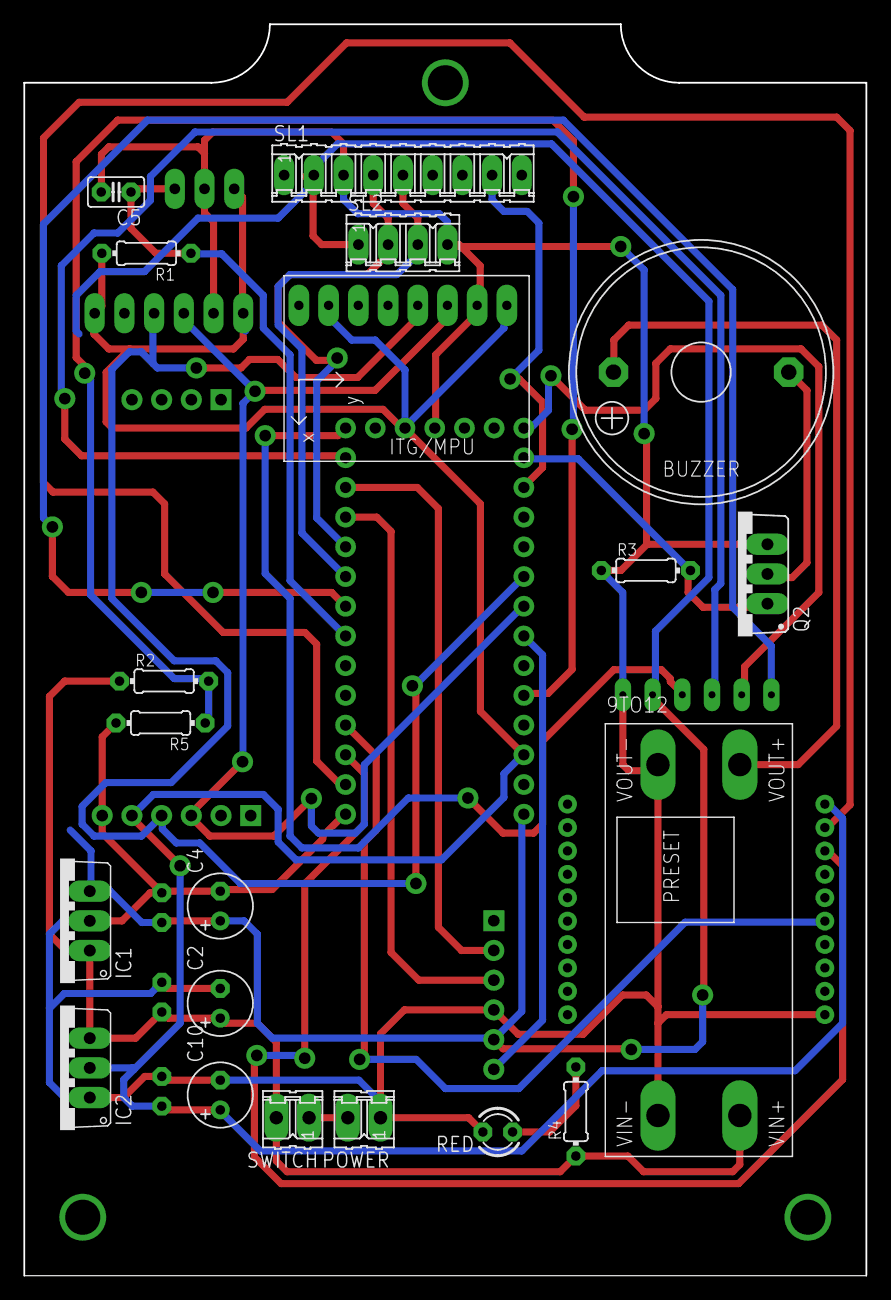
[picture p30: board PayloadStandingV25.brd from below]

Board: 2 copper layers, 72.0 x 107.0 mm, 30 parts (20 on the bottom side), 26 nets.

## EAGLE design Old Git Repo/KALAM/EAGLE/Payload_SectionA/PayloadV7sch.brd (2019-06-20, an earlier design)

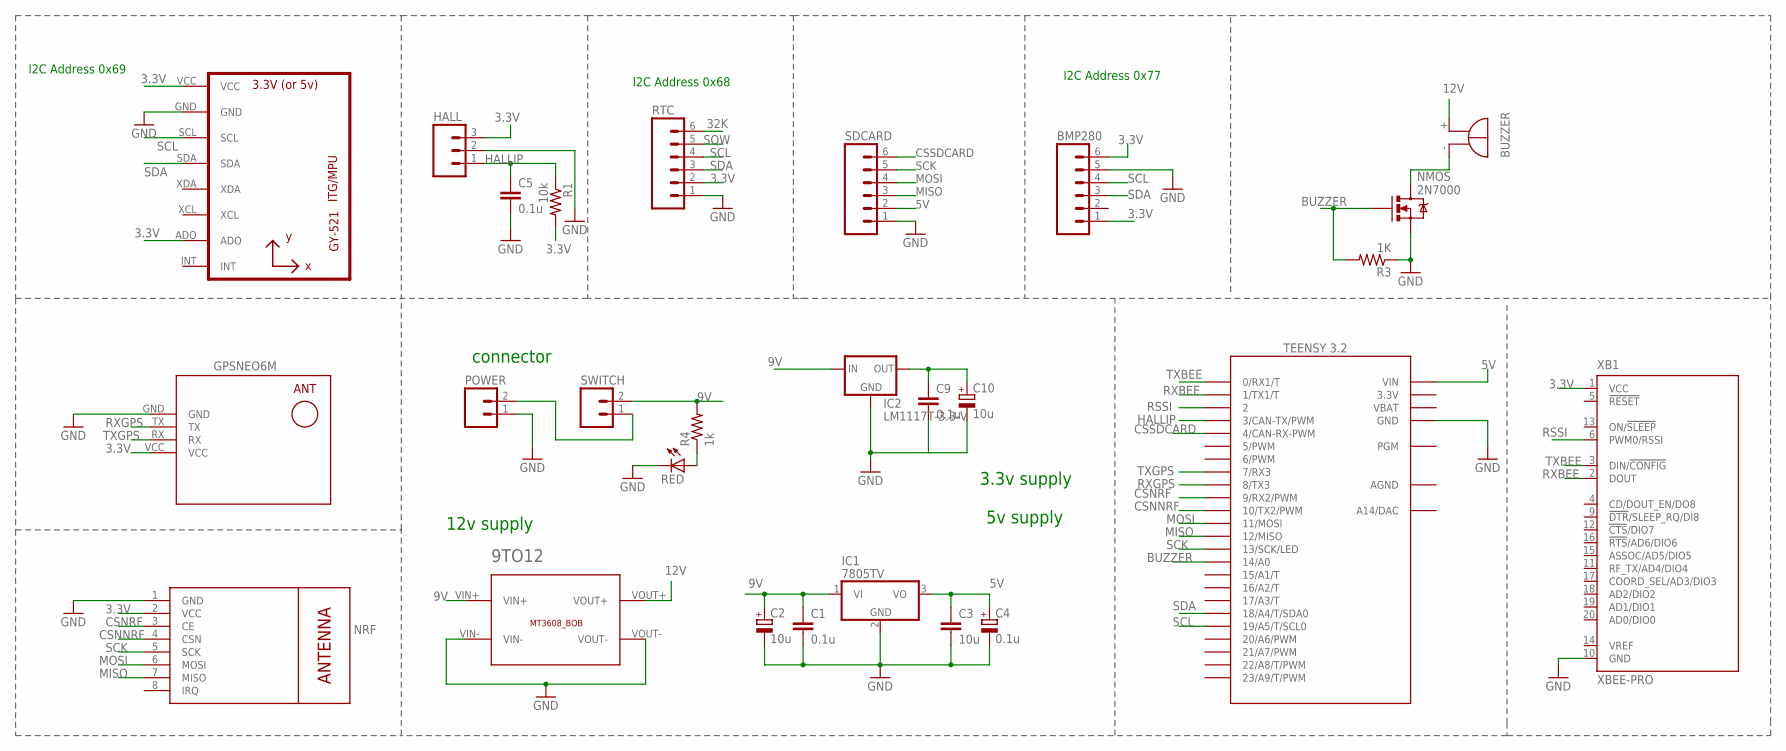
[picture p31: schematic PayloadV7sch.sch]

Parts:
9TO12: BREAKOUTS_MT3608_BOB
BMP280: M06; 06P
C1, C5, C9: 0.1u; C025-025X050
C2, C10: 10u; E2,5-6
C3: 10u; C025-025X050
C4: 0.1u; E2,5-6
HALL: M03; 03P
IC1: 7805TV; TO220V
IC2: LM1117T-3.3-V; TO220V
M1: WIRELESS-NRF24L01
POWER: CEDT_JANUARY_2015_V5_M02; CEDT_JANUARY_2015_V5_02P
Q1: SPARKFUN-DISCRETESEMI_MOSFET-NCHANNEL2N7000; SPARKFUN-DISCRETESEMI_TO-92
R1: 10k; 0204/7
R3: 1K; 0204/7
R4: 1k; 0204/7
RED: red; LED3MM
RTC: M06; 06P
SDCARD: M06; 06P
SG1: BUZZER_EB2209A
SWITCH: CEDT_JANUARY_2015_V5_M02; CEDT_JANUARY_2015_V5_02P
U1: GY-521MPU6050; GY-521
U$2: TEENSY_3.1-3.2_OUTER_ROW; TEENSY_3.0-3.2&LC_OUTER_ROW
U$3: GPS-RECEIVER-NEO6M
XB1: XBEE-PRO

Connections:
3.3V: BMP280.1, BMP280.6, C9.1, C10.+, HALL.3, IC2.2 (OUT), M1.2 (VCC), R1.2, RTC.2, U1.ADO, U1.VCC, U$2.3.3V, U$2.3.3V1 (3.3V), U$3.VCC, XB1.1 (VCC)
5V: C3.1, C4.+, IC1.3 (VO), SDCARD.2, U$2.VIN
9V: 9TO12.VIN+, C1.1, C2.+, IC1.1 (VI), IC2.3 (IN), R4.2
12V: 9TO12.VOUT+, SG1.+
32K: RTC.6
AGND: U$2.AGND
BUZZER: Q1.2 (G), R3.2, U$2.14/A0
CSNNRF: M1.4 (CSN), U$2.10 (10/TX2/PWM)
CSNRF: M1.3 (CE), U$2.9 (9/RX2/PWM)
CSSDCARD: SDCARD.6, U$2.4 (4/CAN-RX-PWM)
GND: 9TO12.VIN-, 9TO12.VOUT-, BMP280.5, C1.2, C2.-, C3.2, C4.-, C5.2, C9.2, C10.-, HALL.2, IC1.2 (GND), IC2.1 (GND), M1.1 (GND), POWER.1, Q1.1 (S), R3.1, RED.K (C), RTC.1, SDCARD.1, U1.GND, U$2.GND, U$2.GND1 (GND), U$3.GND, XB1.10 (GND)
HALLIP: C5.1, HALL.1, R1.1, U$2.3 (3/CAN-TX/PWM)
MISO: M1.7 (MISO), SDCARD.3, U$2.12 (12/MISO)
MOSI: M1.6 (MOSI), SDCARD.4, U$2.11 (11/MOSI)
unnamed: R4.1, RED.A
unnamed: Q1.3 (D), SG1.-
RSSI: U$2.2, XB1.6 (PWM0/RSSI)
RXBEE: U$2.1 (1/TX1/T), XB1.2 (DOUT)
RXGPS: U$2.8 (8/TX3), U$3.TX
SCK: M1.5 (SCK), SDCARD.5, U$2.13 (13/SCK/LED)
SCL: BMP280.4, RTC.4, U1.SCL, U$2.19/A5 (19/A5/T/SCL0)
SDA: BMP280.3, RTC.3, U1.SDA, U$2.18/A4 (18/A4/T/SDA0)
SQW: RTC.5
TXBEE: U$2.0 (0/RX1/T), XB1.3 (DIN/!CONFIG)
TXGPS: U$2.7 (7/RX3), U$3.RX
VBAT: U$2.VBAT

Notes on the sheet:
connector
3.3v supply
5v supply
12v supply
I2C Address 0x77
I2C Address 0x68
I2C Address 0x69

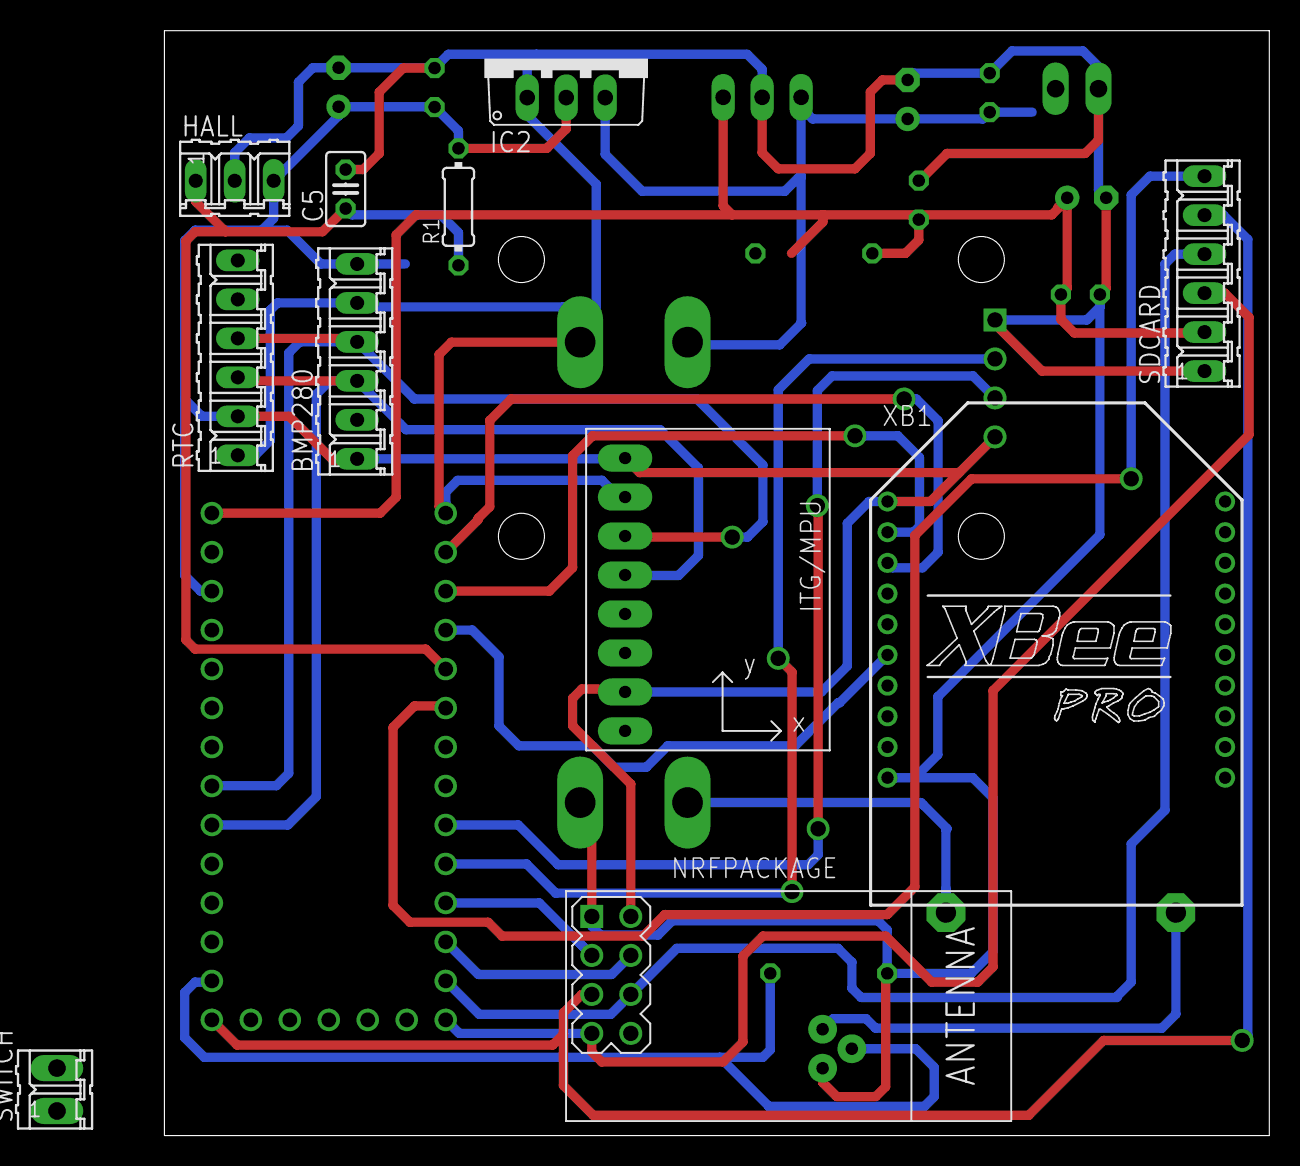
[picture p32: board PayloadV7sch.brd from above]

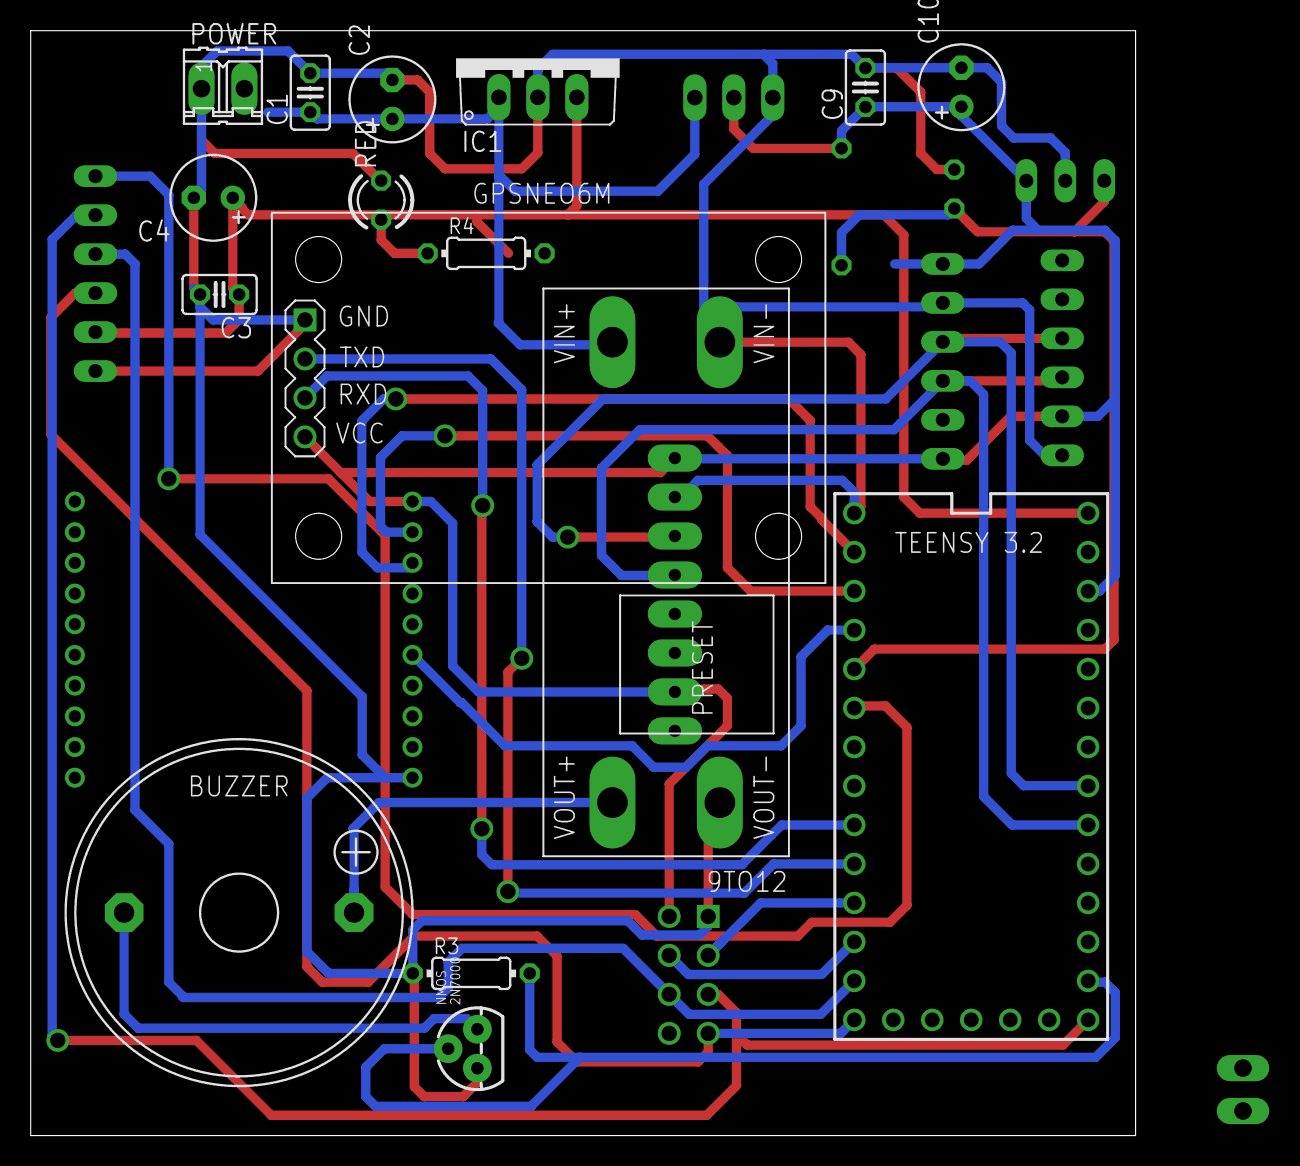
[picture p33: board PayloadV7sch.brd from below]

Board: 2 copper layers, 72.0 x 72.0 mm, 27 parts (16 on the bottom side), 22 nets.

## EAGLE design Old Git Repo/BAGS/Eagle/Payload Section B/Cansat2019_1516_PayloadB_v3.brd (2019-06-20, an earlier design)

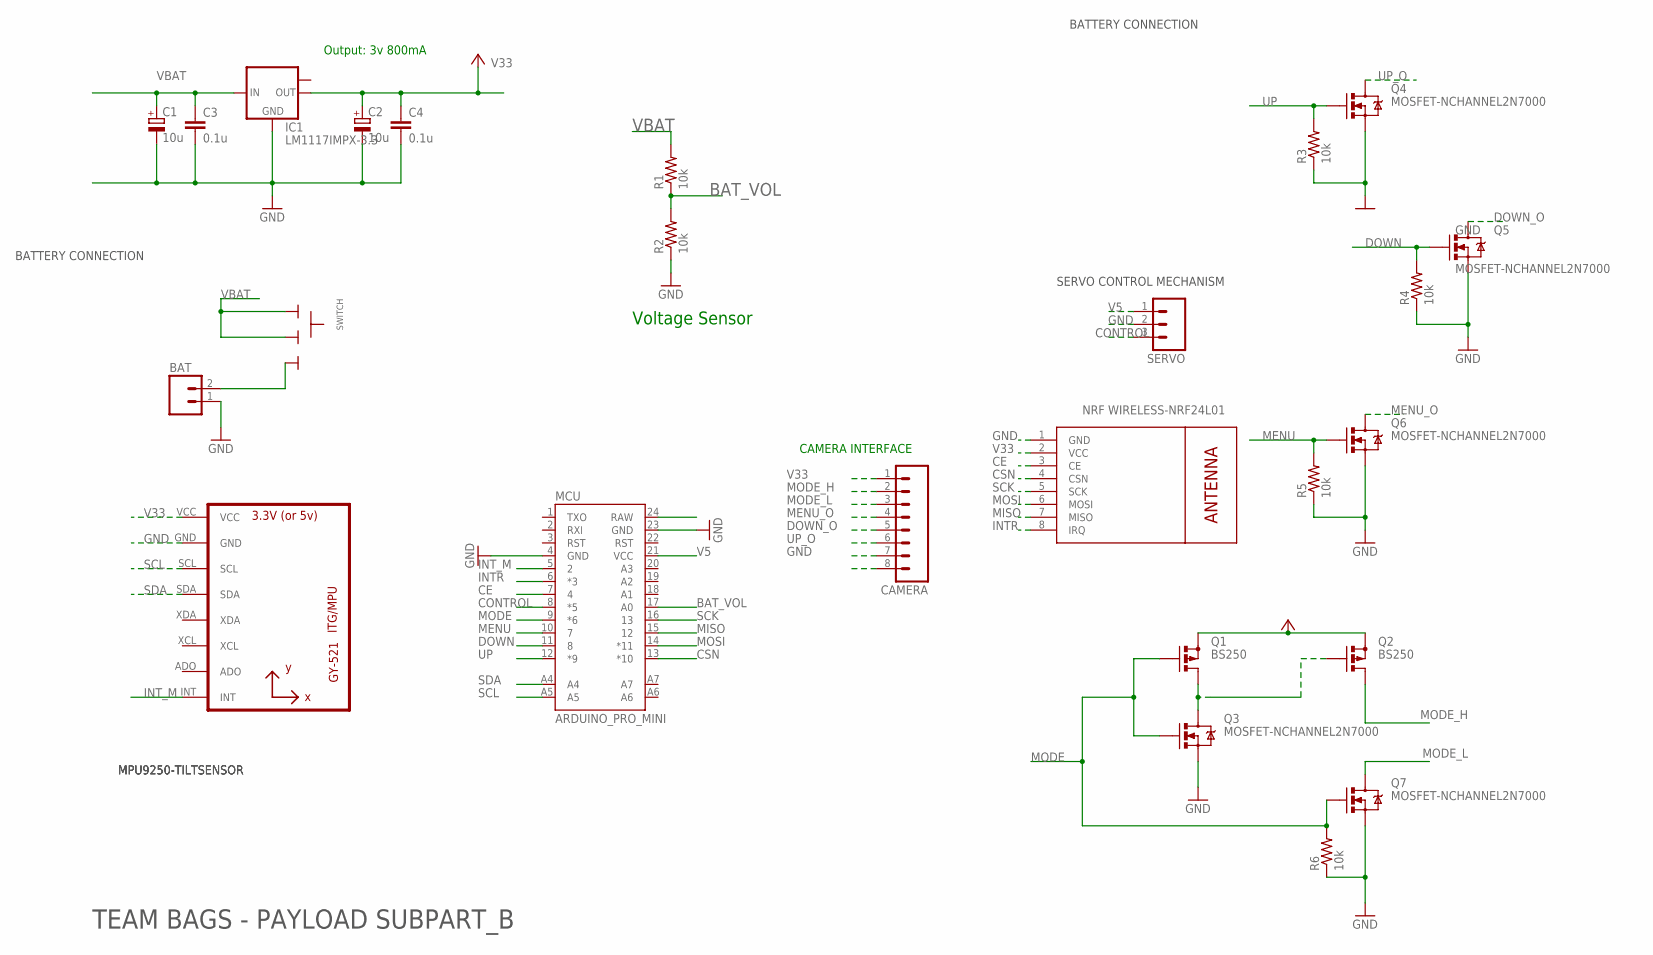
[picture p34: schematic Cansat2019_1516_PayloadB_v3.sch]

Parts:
BAT: M02; 02P
C1, C2: 10u; CT3528
C3, C4: 0.1u; C0805
CAMERA: M08; 08P
IC1: LM1117IMPX-3.3; SOT223
MCU: ARDUINO_PRO_MINI
MPU: GY-521MPU6050; GY-521
NRF: WIRELESS-NRF24L01
Q1, Q2: BS250; SOT54E
Q3, Q4, Q5, Q6, Q7: MOSFET-NCHANNEL2N7000; TO-92
R1, R2, R3, R4, R5, R6: 10k; R0805
SERVO: M03; 03P
SWITCH: SLIDESWITCH-BIG; BIGSWITCH

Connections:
BAT_VOL: MCU.17 (A0), R1.1, R2.2
CE: MCU.7 (4), NRF.3 (CE)
CONTROL: MCU.8 (*5), SERVO.3
CSN: MCU.13 (*10), NRF.4 (CSN)
DOWN: MCU.11 (8), Q5.2 (G), R4.2
DOWN_O: CAMERA.5, Q5.3 (D)
GND: BAT.1, C1.-, C2.-, C3.2, C4.2, CAMERA.7, IC1.1 (GND), MCU.4 (GND), MCU.23 (GND), MPU.GND, NRF.1 (GND), Q3.1 (S), Q4.1 (S), Q5.1 (S), Q6.1 (S), Q7.1 (S), R2.1, R3.1, R4.1, R5.1, R6.1, SERVO.2
INTR: MCU.6 (*3), NRF.8 (IRQ)
INT_M: MCU.5 (2), MPU.INT
MENU: MCU.10 (7), Q6.2 (G), R5.2
MENU_O: CAMERA.4, Q6.3 (D)
MISO: MCU.15 (12), NRF.7 (MISO)
MODE: MCU.9 (*6), Q1.G, Q3.2 (G), Q7.2 (G), R6.2
MODE_H: CAMERA.2, Q2.D
MODE_L: CAMERA.3, Q7.3 (D)
MOSI: MCU.14 (*11), NRF.6 (MOSI)
unnamed: BAT.2, SWITCH.3
unnamed: Q1.D, Q2.G, Q3.3 (D)
SCK: MCU.16 (13), NRF.5 (SCK)
SCL: MCU.A5, MPU.SCL
SDA: MCU.A4, MPU.SDA
UP: MCU.12 (*9), Q4.2 (G), R3.2
UP_O: CAMERA.6, Q4.3 (D)
V5: MCU.21 (VCC), SERVO.1
V33: C2.+, C4.1, CAMERA.1, IC1.2 (OUT), MPU.VCC, NRF.2 (VCC)
VBAT: C1.+, C3.1, IC1.3 (IN), R1.2, SWITCH.1, SWITCH.2
VCC: Q1.S, Q2.S

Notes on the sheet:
Output: 3v 800mA
MPU9250-TILTSENSOR
BATTERY CONNECTION
SERVO CONTROL MECHANISM
CAMERA INTERFACE
TEAM BAGS - PAYLOAD SUBPART_B
Voltage Sensor

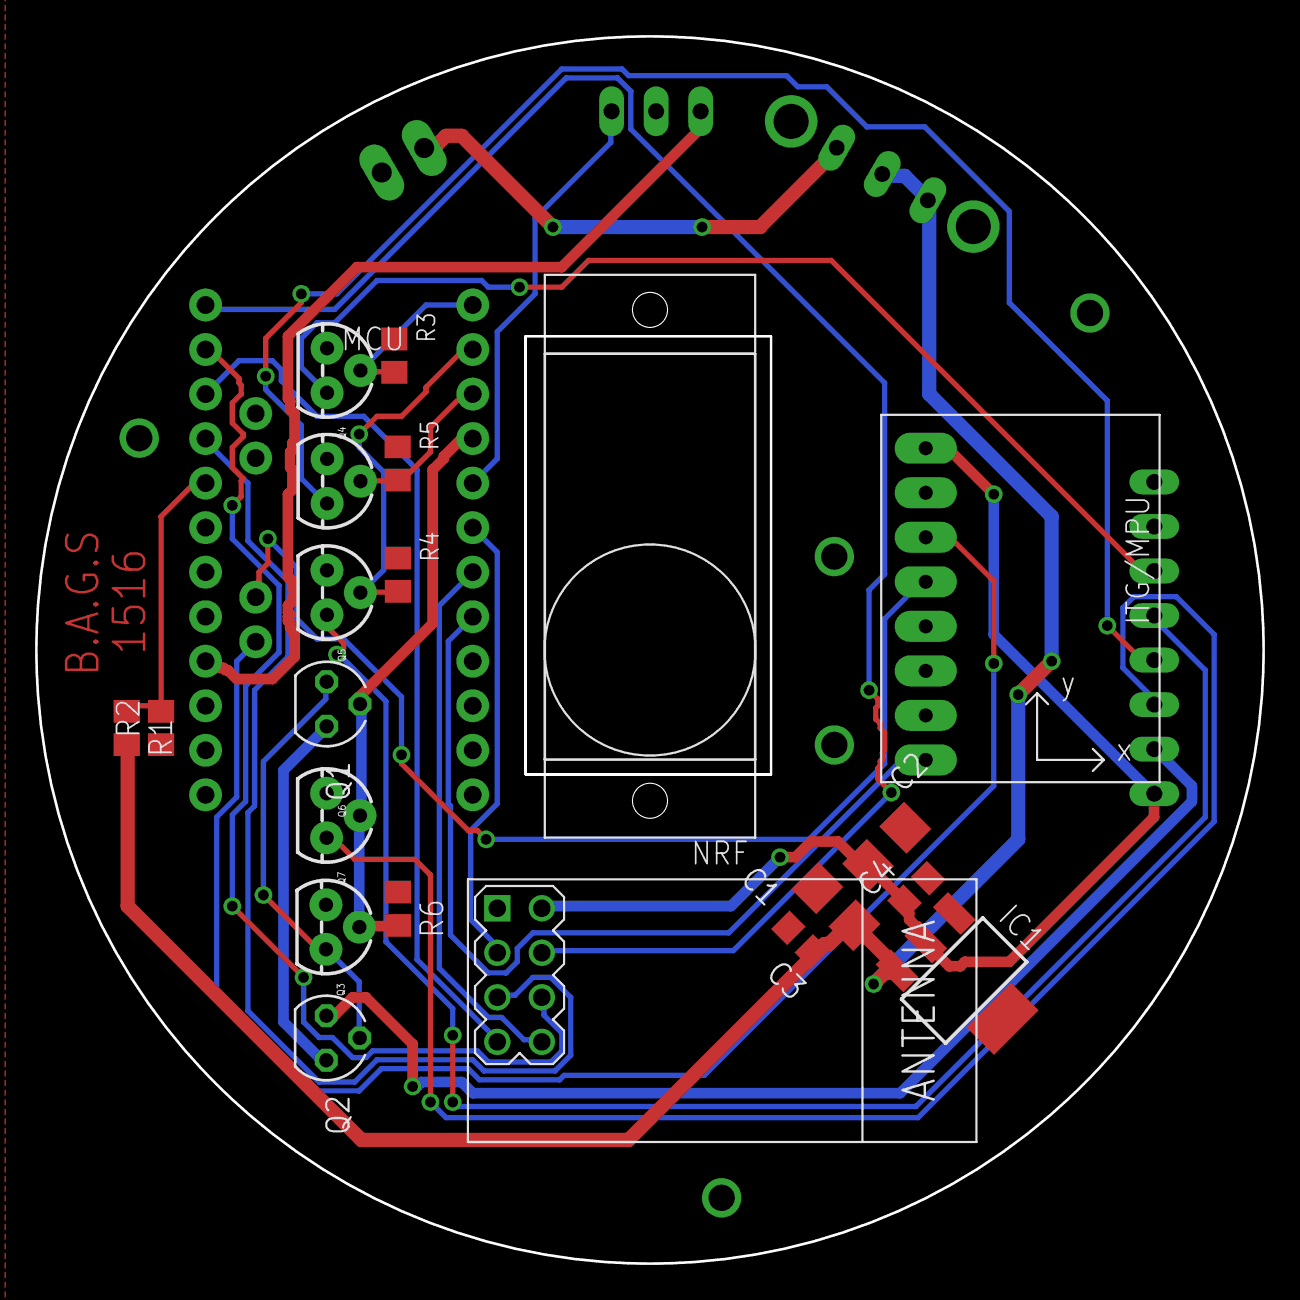
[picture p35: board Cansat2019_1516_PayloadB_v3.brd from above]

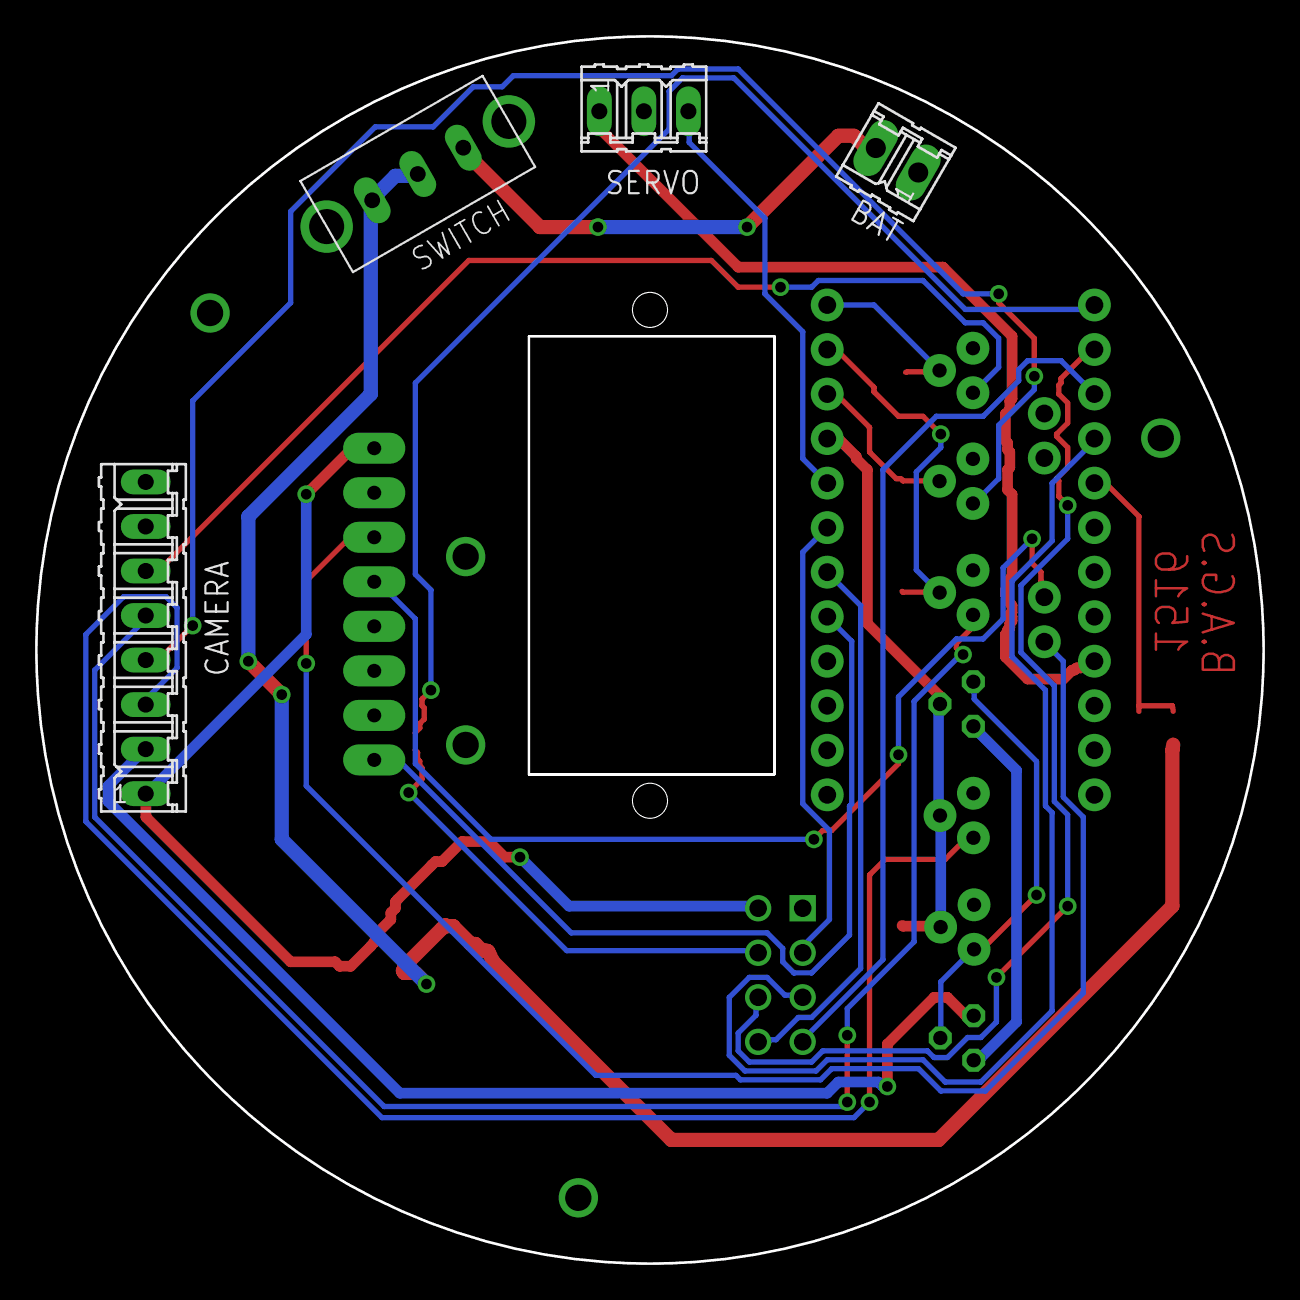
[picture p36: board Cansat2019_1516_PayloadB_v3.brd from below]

Board: 2 copper layers, 70.0 x 70.0 mm, 26 parts (4 on the bottom side), 27 nets.

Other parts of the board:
U$1: SG90_TOP

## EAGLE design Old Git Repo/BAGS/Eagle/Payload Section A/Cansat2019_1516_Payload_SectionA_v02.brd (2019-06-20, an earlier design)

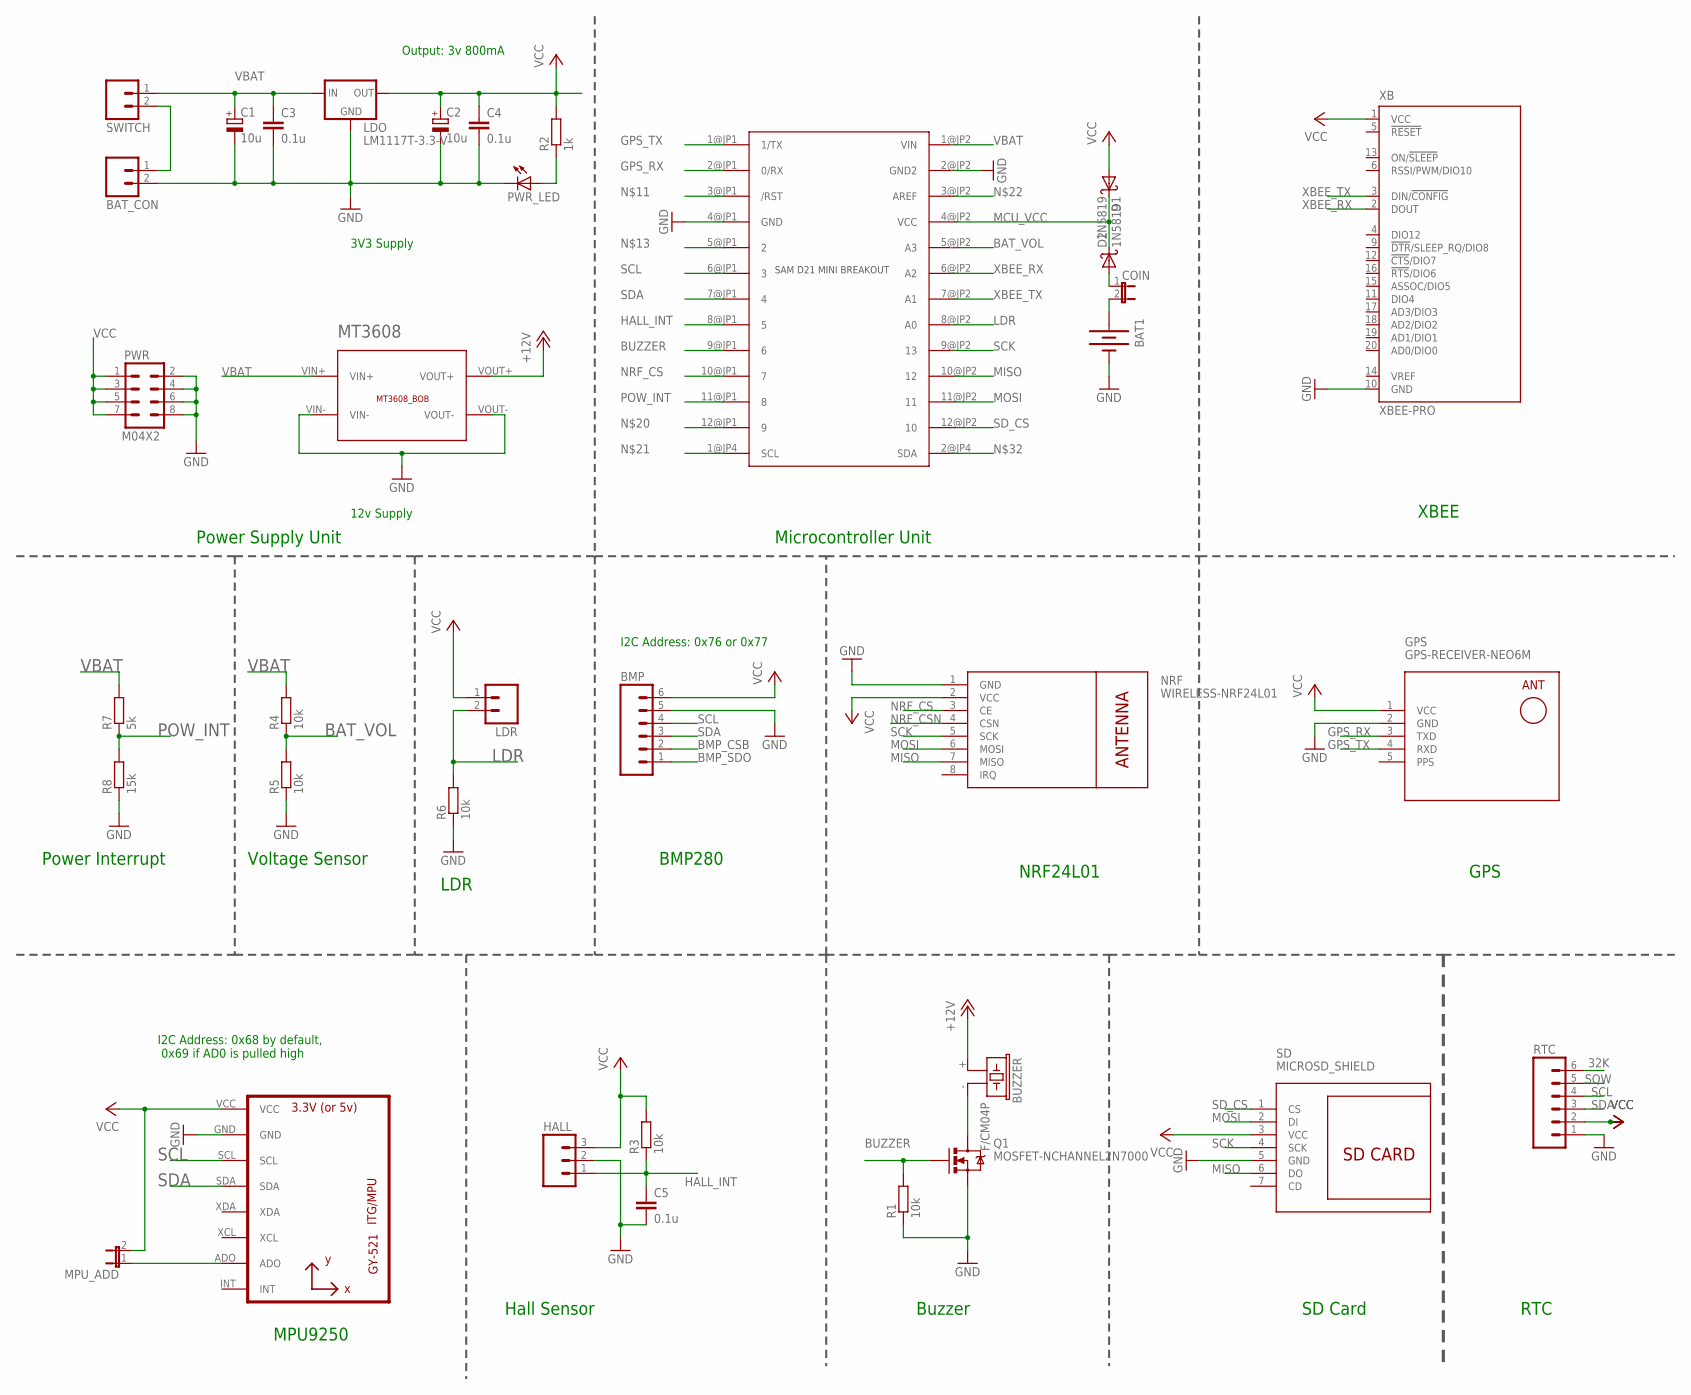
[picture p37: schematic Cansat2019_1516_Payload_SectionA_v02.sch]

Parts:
BAT1: BATTERY20PTH; BATTCOM_20MM_PTH
BAT_CON: M02; 02P
BMP: M06; 06P
BUZZER: F/CM04P
C1, C2: 10u; E2,5-6
C3, C4, C5: 0.1u; C025-025X050
COIN: JUMPER-2PTH; 1X02
D1, D2: 1N5819; DO41-10
GPS: GPS-RECEIVER-NEO6M
HALL: M03; 03P
LDO: LM1117T-3.3-V; TO220V
LDR: M02; 02P
MPU: GY-521MPU6050; GY-521
MPU_ADD: JUMPER-2PTH; 1X02
MT3608: MT3608_BOB
NRF: WIRELESS-NRF24L01
PWR: M04X2; 2X4
PWR_LED: LED3MM
Q1: MOSFET-NCHANNEL2N7000; TO-92
R1, R3, R4, R5, R6: 10k; 0204/7
R2: 1k; 0204/7
R7: 5k; 0204/7
R8: 15k; 0204/7
RTC: M06; 06P
SAMD: SAM_D21_MINI_BREAKOUT; JP1_SPARKFUN-SAMD21-MINI-BREAKOUT-V10
SD: MICROSD_SHIELD
SWITCH: M02; 02P
XB: XBEE-PRO

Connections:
32K: RTC.6
+12V: BUZZER.+ (1), MT3608.VOUT+
BAT_VOL: R4.1, R5.2, SAMD.5@JP2 (A3)
BMP_CSB: BMP.2
BMP_SDO: BMP.1
BUZZER: Q1.2 (G), R1.2, SAMD.9@JP1 (6)
GND: BAT1.2 (-), BAT_CON.2, BMP.5, C1.-, C2.-, C3.2, C4.2, C5.2, GPS.2 (GND), HALL.2, LDO.1 (GND), MPU.GND, MT3608.VIN-, MT3608.VOUT-, NRF.1 (GND), PWR.2, PWR.4, PWR.6, PWR.8, PWR_LED.K (C), Q1.1 (S), R1.1, R5.1, R6.1, R8.1, RTC.1, SAMD.2@JP2 (GND2), SAMD.4@JP1 (GND), SD.5 (GND), XB.10 (GND)
GPS_RX: GPS.3 (TXD), SAMD.2@JP1 (0/RX)
GPS_TX: GPS.4 (RXD), SAMD.1@JP1 (1/TX)
HALL_INT: C5.1, HALL.1, R3.1, SAMD.8@JP1 (5)
LDR: LDR.2, R6.2, SAMD.8@JP2 (A0)
MCU_VCC: D1.C, D2.C, SAMD.4@JP2 (VCC)
MISO: NRF.7 (MISO), SAMD.10@JP2 (12), SD.6 (DO)
MOSI: NRF.6 (MOSI), SAMD.11@JP2 (11), SD.2 (DI)
unnamed: BUZZER.- (2), Q1.3 (D)
unnamed: COIN.1, D2.A
unnamed: PWR_LED.A, R2.1
unnamed: BAT1.1 (+), COIN.2
unnamed: BAT_CON.1, SWITCH.2
unnamed: MPU.ADO, MPU_ADD.1
NRF_CS: NRF.3 (CE), SAMD.10@JP1 (7)
NRF_CSN: NRF.4 (CSN)
POW_INT: R7.1, R8.2, SAMD.11@JP1 (8)
PPS: GPS.5 (PPS)
SCK: NRF.5 (SCK), SAMD.9@JP2 (13), SD.4 (SCK)
SCL: BMP.4, MPU.SCL, RTC.4, SAMD.6@JP1 (3)
SDA: BMP.3, MPU.SDA, RTC.3, SAMD.7@JP1 (4)
SD_CS: SAMD.12@JP2 (10), SD.1 (CS)
SQW: RTC.5
VBAT: C1.+, C3.1, LDO.3 (IN), MT3608.VIN+, R4.2, R7.2, SAMD.1@JP2 (VIN), SWITCH.1
VCC: BMP.6, C2.+, C4.1, D1.A, GPS.1 (VCC), HALL.3, LDO.2 (OUT), LDR.1, MPU.VCC, MPU_ADD.2, NRF.2 (VCC), PWR.1, PWR.3, PWR.5, PWR.7, R2.2, R3.2, RTC.2, SD.3 (VCC), XB.1 (VCC)
XBEE_RX: SAMD.6@JP2 (A2), XB.2 (DOUT)
XBEE_TX: SAMD.7@JP2 (A1), XB.3 (DIN/!CONFIG)

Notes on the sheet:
Power Supply Unit
3V3 Supply
12v Supply
Output: 3v 800mA
Microcontroller Unit
Buzzer
Voltage Sensor
BMP280
GPS
XBEE
MPU9250
SD Card
NRF24L01
LDR
Hall Sensor
I2C Address: 0x76 or 0x77
I2C Address: 0x68 by default, 0x69 if AD0 is pulled high
RTC
Power Interrupt



Board: 2 copper layers, 76.0 x 72.0 mm, 36 parts (14 on the bottom side), 27 nets.

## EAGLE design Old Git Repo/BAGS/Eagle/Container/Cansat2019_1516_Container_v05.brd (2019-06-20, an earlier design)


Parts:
BAT_CON: M02; 02P
BMP280: M06; 06P
C1, C2: 10u; E2,5-6
C3, C4, C7: 0.1u; C025-025X050
D1: 1N4004; DO41-10
EEPROM: 24AA64P; DIL8
K1: CQ1-12V; CQ1
LDO: LM1117T-3.3-V; TO220V
MCU: ARDUINO-PRO-MINI-3.3V#NP; ARDUINO-PRO-MINI#NP
MT3608: MT3608_BOB
NICHROME_WIRE: AK500/2-H
NICH_LED: LED3MM
PWR: M04X2; 2X4
PWR_LED: LED3MM
Q1, Q2: MOSFET-NCHANNEL2N7000; TO-92
R1, R7: 1k; 0204/7
R2, R3: 10k; 0204/7
SG1: EB2209A
SWITCH: M02; 02P

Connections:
+12V: D1.C, K1.1, MT3608.VOUT+, SG1.+
BMP_CSB: BMP280.2
BMP_SDO: BMP280.1
BUZZER: MCU.J7.8 (D2), Q1.2 (G), R2.2
GND: BAT_CON.2, BMP280.5, C1.-, C2.-, C3.2, C4.2, C7.2, EEPROM.1 (A0), EEPROM.2 (A1), EEPROM.3 (A2), EEPROM.4 (GND), LDO.1 (GND), MCU.J3.1 (GND.3), MCU.J6.2 (GND.2), MCU.J7.9 (GND.1), MT3608.VIN-, MT3608.VOUT-, NICHROME_WIRE.2, NICH_LED.K (C), PWR.2, PWR.4, PWR.6, PWR.8, PWR_LED.K (C), Q1.1 (S), Q2.1 (S), R2.1, R3.2
unnamed: Q1.3 (D), SG1.-
unnamed: K1.C, NICHROME_WIRE.1
unnamed: PWR_LED.A, R1.1
unnamed: NICH_LED.A, R7.1
unnamed: BAT_CON.1, SWITCH.2
unnamed: D1.A, K1.2, Q2.3 (D)
NCH_WIR: MCU.J7.1 (D9), Q2.2 (G), R3.1, R7.2
RAW: MCU.J6.1 (RAW)
SCL: BMP280.4, EEPROM.6 (SCL), MCU.J2.2 (A5)
SDA: BMP280.3, EEPROM.5 (SDA), MCU.J2.1 (A4)
VBAT: C1.+, C3.1, K1.NO (S), LDO.3 (IN), MT3608.VIN+, SWITCH.1
VCC: BMP280.6, C2.+, C4.1, C7.1, EEPROM.8 (VCC), LDO.2 (OUT), MCU.J6.4 (VCC), PWR.1, PWR.3, PWR.5, PWR.7, R1.2

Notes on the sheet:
Power Supply Unit
Buzzer
Wire Burning Mechanism
Microcontroller Unit
3V3 Supply
12v Supply
BMP280
internal i2c Pullups
Output: 3v 800mA
Device Address: 0x50
EEPROM
Device Address: 0x76 or 0x77


Board: 2 copper layers, 76.2 x 47.9 mm, 25 parts (0 on the bottom side), 14 nets.

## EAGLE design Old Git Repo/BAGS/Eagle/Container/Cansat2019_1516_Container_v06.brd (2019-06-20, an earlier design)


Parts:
BAT_CON: M02; 02P
BMP280: M06; 06P
BUZZER: EB2209A
C7: 0.1u; C025-025X050
D1: 1N4004; DO41-10
EEPROM: 24AA64P; DIL8
MCU: ARDUINO_PRO_MINI
MT3608: MT3608_BOB
NICHROME_WIRE: AK500/2-H
NICH_LED: LED3MM
Q1, Q2: MOSFET-NCHANNEL2N7000; TO-92
R2, R3: 10k; 0204/7
R7: 1k; 0204/7
RELAY: CQ1-12V; CQ1
SWITCH: M02; 02P

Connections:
+12V: BUZZER.+, D1.C, MT3608.VOUT+, RELAY.1
BMP_CSB: BMP280.2
BMP_SDO: BMP280.1
BUZZER: MCU.18 (A1), Q1.2 (G), R2.2
GND: BAT_CON.2, BMP280.5, C7.2, EEPROM.1 (A0), EEPROM.2 (A1), EEPROM.3 (A2), EEPROM.4 (GND), MCU.4 (GND), MCU.23 (GND), MT3608.VIN-, MT3608.VOUT-, NICHROME_WIRE.2, NICH_LED.K (C), Q1.1 (S), Q2.1 (S), R2.1, R3.2
unnamed: BUZZER.-, Q1.3 (D)
unnamed: NICHROME_WIRE.1, RELAY.C
unnamed: NICH_LED.A, R7.1
unnamed: BAT_CON.1, SWITCH.2
unnamed: D1.A, Q2.3 (D), RELAY.2
NCH_WIR: MCU.19 (A2), Q2.2 (G), R3.1, R7.2
SCL: BMP280.4, EEPROM.6 (SCL), MCU.A5
SDA: BMP280.3, EEPROM.5 (SDA), MCU.A4
VBAT: MCU.24 (RAW), MT3608.VIN+, RELAY.NO (S), SWITCH.1
VCC: BMP280.6, C7.1, EEPROM.8 (VCC), MCU.21 (VCC)

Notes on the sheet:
Power Supply Unit
Buzzer
Wire Burning Mechanism
Microcontroller Unit
12v Supply
BMP280
Device Address: 0x50
EEPROM
Device Address: 0x76 or 0x77
internal i2c Pullups


Board: 2 copper layers, 67.3 x 42.9 mm, 17 parts (0 on the bottom side), 13 nets.

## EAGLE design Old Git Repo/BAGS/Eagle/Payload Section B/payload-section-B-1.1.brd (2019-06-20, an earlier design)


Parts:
9VBAT: POWER_CON; NEB21R
C1, C2, C5, C6: 10u; CT6032
C3, C4, C7, C8: 0.1u; C0805
IC1: V_REG_78XX-TO-220; TO-220-ALT
IC2: LM1117-3.3V-SOT223; SOT223
JP1: M08; 08P
M1: ARDUINO-PRO-MINI-3.3V; ARDUINO-PRO-MINI
M2: WIRELESS-NRF24L01
PWR_LED1: LED3MM
Q1, Q2: BS250; SOT54E
Q3, Q4, Q5, Q6, Q7: MOSFET-NCHANNEL2N7000; TO-92
R2: 1k; R0805
R3, R4, R5: 10k; R0805
SL1: M03; 03P
U2: GY-521MPU6050; GY-521
U$2: SLIDESWITCH-BIG; BIGSWITCH

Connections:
A0: M1.J6.8 (A0)
CE: M1.J7.6 (D4), M2.3 (CE)
CONTROL: M1.J7.5 (D5), SL1.3
CSN: M1.J6.12 (D10), M2.4 (CSN)
DOWN: M1.J7.2 (D8), Q5.2 (G), R4.2
DOWN_O: JP1.5, Q5.3 (D)
GND: 9VBAT.-, 9VBAT.C, C1.-, C2.-, C3.2, C4.2, C5.-, C6.-, C7.2, C8.2, IC1.GND, IC2.1 (GND), JP1.7, M1.J6.2 (GND.2), M1.J7.9 (GND.1), M2.1 (GND), PWR_LED1.K (C), Q3.1 (S), Q4.1 (S), Q5.1 (S), Q6.1 (S), Q7.1 (S), R3.1, R4.1, R5.1, SL1.2, U2.ADO, U2.GND
INTM: M1.J7.8 (D2), U2.INT
INTR: M1.J7.7 (D3), M2.8 (IRQ)
MENU: M1.J7.3 (D7), Q6.2 (G), R5.2
MENU_O: JP1.4, Q6.3 (D)
MISO: M1.J6.10 (D12), M2.7 (MISO)
MODE: M1.J7.4 (D6), Q1.G, Q3.2 (G), Q7.2 (G)
MODE_H: Q2.D
MODE_H_O: JP1.2
MODE_L: Q7.3 (D)
MODE_L_O: JP1.3
MOSI: M1.J6.11 (D11), M2.6 (MOSI)
unnamed: 9VBAT.+, U$2.3
unnamed: Q1.D, Q2.G, Q3.3 (D)
unnamed: PWR_LED1.A, R2.1
P1: M1.J1.6 (P_DTR)
P2: M1.J1.5 (P_TXD)
P3: M1.J1.4 (P_RXD)
P4: M1.J1.3 (P_VCC)
P5: M1.J1.2 (P_CTS)
P6: M1.J1.1 (P_GND)
RAW: M1.J6.1 (RAW)
SCK: M1.J6.9 (D13), M2.5 (SCK)
SCL: M1.J2.2 (A5), U2.SCL
SDA: M1.J2.1 (A4), U2.SDA
UP: M1.J7.1 (D9), Q4.2 (G), R3.2
UP_O: JP1.6, Q4.3 (D)
V5: C6.+, C8.1, IC1.OUT, M1.J6.4 (VCC), R2.2, SL1.1
V33: C2.+, C4.1, IC2.2 (VOUT), JP1.1, M2.2 (VCC), U2.VCC
VBAT: C1.+, C3.1, C5.+, C7.1, IC1.IN, IC2.3 (VIN), U$2.1, U$2.2
VCC: Q1.S, Q2.S

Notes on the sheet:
Output: 3v 800mA
Output: 5v 2200mA
MPU9250-TILTSENSOR
BATTERY CONNECTION
SERVO CONTROL MECHANISM
CAMERA INTERFACE
TEAM BAGS - PAYLOAD SUBPART_B



Board: 2 copper layers, 70.0 x 70.0 mm, 30 parts (4 on the bottom side), 25 nets.

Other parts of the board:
U$1: SG90_TOP

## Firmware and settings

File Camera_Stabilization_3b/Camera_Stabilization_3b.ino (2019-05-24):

/*
  DIY Gimbal - MPU6050 Arduino Tutorial
  by Dejan, www.HowToMechatronics.com
  Code based on the MPU6050_DMP6 example from the i2cdevlib library by Jeff Rowberg:
  https://github.com/jrowberg/i2cdevlib
*/
// I2Cdev and MPU6050 must be installed as libraries, or else the .cpp/.h files
// for both classes must be in the include path of your project
#include "I2Cdev.h"

#include "MPU6050_6Axis_MotionApps20.h"
//#include "MPU6050.h" // not necessary if using MotionApps include file

// Arduino Wire library is required if I2Cdev I2CDEV_ARDUINO_WIRE implementation
// is used in I2Cdev.h
#if I2CDEV_IMPLEMENTATION == I2CDEV_ARDUINO_WIRE
  #include "Wire.h"
#endif

#include <Servo.h>
// class default I2C address is 0x68
// specific I2C addresses may be passed as a parameter here
// AD0 low = 0x68 (default for SparkFun breakout and InvenSense evaluation board)
// AD0 high = 0x69
MPU6050 mpu;                                          //Making a MPU6050 object!
//MPU6050 mpu(0x69);                                  // <-- use for AD0 high

// Define the 3 servo motors
Servo servo0;                     //SERVO ZERO IS FOR YAW:
int servo0Speed = 1500;
//Servo servo1;
//Servo servo2;

float correct;
int j = 0;

#define OUTPUT_READABLE_YAWPITCHROLL

#define INTERRUPT_PIN 2  // use pin 2 on Arduino Uno & most boards

bool blinkState = false;

// MPU control/status vars
bool dmpReady = false;  // set true if DMP init was successful
uint8_t mpuIntStatus;   // holds actual interrupt status byte from MPU
uint8_t devStatus;      // return status after each device operation (0 = success, !0 = error)
uint16_t packetSize;    // expected DMP packet size (default is 42 bytes)
uint16_t fifoCount;     // count of all bytes currently in FIFO
uint8_t fifoBuffer[64]; // FIFO storage buffer

// orientation/motion vars
Quaternion q;           // [w, x, y, z]         quaternion container
VectorInt16 aa;         // [x, y, z]            accel sensor measurements
VectorInt16 aaReal;     // [x, y, z]            gravity-free accel sensor measurements
VectorInt16 aaWorld;    // [x, y, z]            world-frame accel sensor measurements
VectorFloat gravity;    // [x, y, z]            gravity vector
float euler[3];         // [psi, theta, phi]    Euler angle container
float ypr[3];           // [yaw, pitch, roll]   yaw/pitch/roll container and gravity vector

// packet structure for InvenSense teapot demo
uint8_t teapotPacket[14] = { '$', 0x02, 0, 0, 0, 0, 0, 0, 0, 0, 0x00, 0x00, '\r', '\n' };



// ================================================================
// ===               INTERRUPT DETECTION ROUTINE                ===
// ================================================================

volatile bool mpuInterrupt = false;     // indicates whether MPU interrupt pin has gone high
void dmpDataReady() {
  mpuInterrupt = true;
}

// ================================================================
// ===               MY CODE FOR CALCULATING GYRO ERRORS        ===
// ===              CODE TAKEN FROM HOW TO MECHTRONICS          ===
// ================================================================
  const int MPUAddr = 0x68;
  float AccX, AccY, AccZ;
  float GyroX, GyroY, GyroZ;
  float accAngleX, accAngleY, gyroAngleX, gyroAngleY, gyroAngleZ;
  float roll, pitch, yaw;
  float AccErrorX, AccErrorY, GyroErrorX, GyroErrorY, GyroErrorZ;
  float elapsedTime, currentTime, previousTime;
  int c = 0;

  void calculate_IMU_error() {
  // We can call this funtion in the setup section to calculate the accelerometer and gyro data error. From here we will get the error values used in the above equations printed on the Serial Monitor.
  // Note that we should place the IMU flat in order to get the proper values, so that we then can the correct values
  // Read accelerometer values 200 times
    while (c < 200) {
      Wire.beginTransmission(MPUAddr);
      Wire.write(0x3B);
      Wire.endTransmission(false);
      Wire.requestFrom(MPUAddr, 6, true);
      AccX = (Wire.read() << 8 | Wire.read()) / 16384.0 ;
      AccY = (Wire.read() << 8 | Wire.read()) / 16384.0 ;
      AccZ = (Wire.read() << 8 | Wire.read()) / 16384.0 ;
      // Sum all readings
      AccErrorX = AccErrorX + ((atan((AccY) / sqrt(pow((AccX), 2) + pow((AccZ), 2))) * 180 / PI));
      AccErrorY = AccErrorY + ((atan(-1 * (AccX) / sqrt(pow((AccY), 2) + pow((AccZ), 2))) * 180 / PI));
      c++;
    }
    //Divide the sum by 200 to get the error value
    AccErrorX = AccErrorX / 200;
    AccErrorY = AccErrorY / 200;
    c = 0;
    // Read gyro values 200 times
    while (c < 200) {
      Wire.beginTransmission(MPUAddr);
      Wire.write(0x43);
      Wire.endTransmission(false);
      Wire.requestFrom(MPUAddr, 6, true);
      GyroX = Wire.read() << 8 | Wire.read();
      GyroY = Wire.read() << 8 | Wire.read();
      GyroZ = Wire.read() << 8 | Wire.read();
      // Sum all readings
      GyroErrorX = GyroErrorX + (GyroX / 131.0);
      GyroErrorY = GyroErrorY + (GyroY / 131.0);
      GyroErrorZ = GyroErrorZ + (GyroZ / 131.0);
      c++;
    }
    //Divide the sum by 200 to get the error value
    GyroErrorX = GyroErrorX / 200;
    GyroErrorY = GyroErrorY / 200;
    GyroErrorZ = GyroErrorZ / 200;
  // Print the error values on the Serial Monitor
  Serial.print("AccErrorX: ");
  Serial.println(AccErrorX);
  Serial.print("AccErrorY: ");
  Serial.println(AccErrorY);
  Serial.print("GyroErrorX: ");
  Serial.println(GyroErrorX);
  Serial.print("GyroErrorY: ");
  Serial.println(GyroErrorY);
  Serial.print("GyroErrorZ: ");
  Serial.println(GyroErrorZ);
}

////////////////////////////////////////////////////////////////////
//         CALVULATE YAW

//call repeatedly in loop, only updates after a certain time interval
//returns true if update happened
////////////////////////////////////////////////////////////////////
void calculateYaw() {
  // if programming failed, don't try to do anything
  if (!dmpReady) return;

  // wait for MPU interrupt or extra packet(s) available
  while (!mpuInterrupt && fifoCount < packetSize) {
    if (mpuInterrupt && fifoCount < packetSize) {
      // try to get out of the infinite loop
      fifoCount = mpu.getFIFOCount();
    }
  }

  // reset interrupt flag and get INT_STATUS byte
  mpuInterrupt = false;
  mpuIntStatus = mpu.getIntStatus();

  // get current FIFO count
  fifoCount = mpu.getFIFOCount();

  // check for overflow (this should never happen unless our code is too inefficient)
  if ((mpuIntStatus & _BV(MPU6050_INTERRUPT_FIFO_OFLOW_BIT)) || fifoCount >= 1024) {
    // reset so we can continue cleanly
    mpu.resetFIFO();
    fifoCount = mpu.getFIFOCount();
    Serial.println(F("FIFO overflow!"));

    // otherwise, check for DMP data ready interrupt (this should happen frequently)
  } else if (mpuIntStatus & _BV(MPU6050_INTERRUPT_DMP_INT_BIT)) {
    // wait for correct available data length, should be a VERY short wait
    while (fifoCount < packetSize) fifoCount = mpu.getFIFOCount();

    // read a packet from FIFO
    mpu.getFIFOBytes(fifoBuffer, packetSize);

    // track FIFO count here in case there is > 1 packet available
    // (this lets us immediately read more without waiting for an interrupt)
    fifoCount -= packetSize;

    // Get Yaw, Pitch and Roll values
#ifdef OUTPUT_READABLE_YAWPITCHROLL
    mpu.dmpGetQuaternion(&q, fifoBuffer);
    mpu.dmpGetGravity(&gravity, &q);
    mpu.dmpGetYawPitchRoll(ypr, &q, &gravity);

    // Yaw, Pitch, Roll values - Radians to degrees
    ypr[0] = ypr[0] * 180 / M_PI;
    ypr[1] = ypr[1] * 180 / M_PI;
    ypr[2] = ypr[2] * 180 / M_PI;
#endif
  }
}//void calculateYaw

// ================================================================
// ===                      CAMERA RELATED                       ===
// ================================================================
#define LONG_PRESS 3000
#define PIN_CAMERA 4
long cameraStartime = 0;
int cameraState = 0;

void setupCamera(){
  pinMode(PIN_CAMERA,OUTPUT);
  cameraStartime = millis();
}

void switchOnOffCamera(){
  digitalWrite(PIN_CAMERA,HIGH);
  Serial.write("LP");
  delay(LONG_PRESS);
  digitalWrite(PIN_CAMERA,LOW);
  cameraState = 1;
}

// ================================================================
// ===                      INITIAL SETUP                       ===
// ================================================================

void setup() {

  setupCamera();
  switchOnOffCamera();
  
  // join I2C bus (I2Cdev library doesn't do this automatically)
#if I2CDEV_IMPLEMENTATION == I2CDEV_ARDUINO_WIRE
  Wire.begin();
  Wire.setClock(400000); // 400kHz I2C clock. Comment this line if having compilation difficulties
#elif I2CDEV_IMPLEMENTATION == I2CDEV_BUILTIN_FASTWIRE
  Fastwire::setup(400, true);
#endif

  // initialize serial communication
  // (115200 chosen because it is required for Teapot Demo output, but it's
  // really up to you depending on your project)
  Serial.begin(38400);
  while (!Serial); // wait for Leonardo enumeration, others continue immediately

//   ================================================================
// ===              InSETUP:  MY CODE FOR CALCULATING GYRO ERRORS        ===
// ===              In SETUP:CODE TAKEN FROM HOW TO MECHTRONICS          ===
// ================================================================
  Wire.beginTransmission(MPUAddr);       // Start communication with MPUAddr6050 // MPUAddr=0x68
  Wire.write(0x6B);                  // Talk to the register 6B
  Wire.write(0x00);                  // Make reset - place a 0 into the 6B register
  Wire.endTransmission(true);        //end the transmission

  // Call this function if you need to get the IMU error values for your module
  calculate_IMU_error();
// ================================================================
   //End of my code:
// ================================================================


    
  // initialize device
  //Serial.println(F("Initializing I2C devices..."));
  mpu.initialize();
  pinMode(INTERRUPT_PIN, INPUT);
  devStatus = mpu.dmpInitialize();
  
  // supply your own gyro offsets here, scaled for min sensitivity
  //Commenting there's
//  mpu.setXGyroOffset(17);
//  mpu.setYGyroOffset(-69);
//  mpu.setZGyroOffset(27);
//  mpu.setZAccelOffset(1551); // 1688 factory default for my test chip

  //These are mine:
  mpu.setXGyroOffset(GyroErrorX);
  mpu.setYGyroOffset(GyroErrorY);
  mpu.setZGyroOffset(GyroErrorZ);
  mpu.setZAccelOffset(725); // 1688 factory default for my test chip

  // make sure it worked (returns 0 if so)
  if (devStatus == 0) {
    // turn on the DMP, now that it's ready
    // Serial.println(F("Enabling DMP..."));
    mpu.setDMPEnabled(true);

    attachInterrupt(digitalPinToInterrupt(INTERRUPT_PIN), dmpDataReady, RISING);
    mpuIntStatus = mpu.getIntStatus();

    // set our DMP Ready flag so the main loop() function knows it's okay to use it
    //Serial.println(F("DMP ready! Waiting for first interrupt..."));
    dmpReady = true;

    // get expected DMP packet size for later comparison
    packetSize = mpu.dmpGetFIFOPacketSize();
  } else {
    // ERROR!
    // 1 = initial memory load failed
    // 2 = DMP configuration updates failed
    // (if it's going to break, usually the code will be 1)
    // Serial.print(F("DMP Initialization failed (code "));
    //Serial.print(devStatus);
    //Serial.println(F(")"));
  }

  // Define the pins to which the 3 servo motors are connected
  servo0.attach(10);
//  servo1.attach(9);
//  servo2.attach(8);
  Serial.println("SETUP FINISHED");

  //SELF CALLIBRATION:
  Serial.println("SELF CALLIBRATION STARTED");
  //For 2000 times, we'll record yaw values
  for(int i=0; i<2000; i++){
    calculateYaw();
    correct = ypr[0];
  }
  //This will indicate that callibration is finished:
  pinMode(13,OUTPUT);
  digitalWrite(13,HIGH);
  
}

// ================================================================
// ===                     LOOP                       ===
// ================================================================

void loop() {
  calculateYaw();
  ypr[0] = ypr[0] - correct;

  Serial.print(String(ypr[0]) + "\t");
  
  //TO KEEP RANGE OF YAW FROM -180 to 180
  if(ypr[0] > 180){
    ypr[0] = 360 - ypr[0];
  }else if(ypr[0] < -180){
    ypr[0] = 360 + ypr[0];
  }

  Serial.println(String(ypr[0]));  
  rotateServo();  

  //Switching off the camera after 1 minute
  if((millis() - cameraStartime) > 120000 && cameraState == 1){
    switchOnOffCamera();  
    digitalWrite(13,LOW); 
    cameraState = 0;
  }
}

void rotateServo(){
  if(ypr[0] > 10){
    servo0Speed = map(ypr[0], 0, 180, 1425, 1395);
    rotateServoClockwise(servo0Speed);
  }else if(ypr[0] < -10){
    servo0Speed = map(ypr[0], -180, 0, 1585, 1555);
    rotateServoAntiClockwise(servo0Speed);
  }else{
    stopServo();
  }
}

//Continuous servo rotates clockwise for Servo.write() value between 0 to 89;
void rotateServoClockwise(int servoSpeed){
  servo0.writeMicroseconds(servoSpeed);
}

//Continuous servo rotates clockwise for Servo.write() value between 180 down to 91;
void rotateServoAntiClockwise(int servoSpeed){
  servo0.writeMicroseconds(servoSpeed);
}

void stopServo(){
  servo0.writeMicroseconds(1500);
}

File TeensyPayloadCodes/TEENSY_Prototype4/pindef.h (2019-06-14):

#include <MPU6050_tockn.h>
#include <RTClib.h>    //RTC Library
#include <Arduino.h>   // required before wiring_private.h
#include <Wire.h>                            
#include <SPI.h>
#include <SD.h>
#include <TinyGPS++.h>

//BMP: I2C pins : SCL-19, SDA-18 and Vin = 3.3V, SDO - HIGH (SHORT TO Vin)
//SPI : SS - 10, SCK -13, MOSI-11, MISO-12

#include <Adafruit_BMP280.h> //BMP Library
//#include "MPU6050_tockn.h"
#include "packet.h"

#define voltagePin A8

#define gps_uart Serial3
#define GPSBaud 9600

#define xbee Serial1
#define XBEEBaud 9600
#define XBEE_INTERRUPT_PIN 2

#define SD_SELECT 6

#define NUMBEROFMAGNETS 1           //Number of magnets on fan 
#define HALLPIN 5

#define BUZZERPIN 14

#define LOG_MISSION	//enable this to log mission events to SD card
#define SER_DEBUG		//enable this to get debug info in serial monitor

#undef SER_DEBUG


#define SWITCHONCAMERASERVO 2
#define SWITCHONCAMERA 3

#define TEAM_ID 3279		//TEAM KALAM

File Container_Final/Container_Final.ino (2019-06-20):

#include "Adafruit_BMP280.h"

#include <Wire.h>
//#include <SFE_BMP180.h>
#include <Servo.h>
#include <EEPROM.h>
#define BOOT 1
#define ACCENT 2
#define DEPLOYMENT 3
#define DESCENT 4
#define END 5

#define eeprom 0x50

#define test

# define DEBUG

Adafruit_BMP280 bmp; // I2C

 int oldSoftState = BOOT;
const int ldr_pin = A0;
const int buzzer_pin = A1;
//SFE_BMP180 bmp180;
int prev_Alt = 0;
int software_state = 1;
double a = 0;
long addr = 0;
Servo myservo;
int angle = 0;
byte value;

#define servo_delay 800


//http://www.hobbytronics.co.uk/eeprom-page-write
//http://www.hobbytronics.co.uk/arduino-external-eeprom

//http://www.jucetechnology.com/wordpress/simple-burglar-save-sensor-code-eeprom/

double baseline; // baseline pressure

volatile float ground_altitude = 0;
float relAltitude = 0;

void setup()
{
  initBmp();
  setGroundAltitude();
  
  int oldSoftState = BOOT;

  Serial.begin(9600);
  Serial.println("REBOOT");


  Wire.begin();
  pinMode(buzzer_pin, OUTPUT);
  digitalWrite(buzzer_pin,LOW);

 
  pinMode(ldr_pin, INPUT);
  myservo.attach(9);
  
}

void loop()
{
  a = height;
  
  EEPROM.write(addr, a);

  Serial.println("HEYY");

  //Serial.println(readEEPROM(eeprom, address), DEC);
  //address+=4;

  byte value = EEPROM.read(addr);
  Serial.print(addr);
  Serial.print("\t");
  Serial.print(value, DEC);
  Serial.println();
  addr = addr + 1;
  if (addr == EEPROM.length()) {
    addr = 0;
  }


  Serial.print("relative altitude: ");
  float height = getBMPAltitute();
  if (a >= 0.0) Serial.print(" "); // add a space for positive numbers
  Serial.print(height, 1);
  Serial.print(" meters, ");

  setSoftwareState();
  delay(1000);
}




//As code begins,                         : Software state = 1 = BOOT;
//When prev_Alt > 5m and currAlt > prev_Alt : Software state = 2 = ACCENT
//When presAlt >670 and currAlt < prev_Alt : Software state = 3 = DEPLOYMENT (from rocket)
//When presAlt <450 and currAlt < prev_Alt : Software state = 4 = DESCENT (seperated from Container)
//When presAlt <5 and   currAlt < prev_Alt : Software state = 5 = END


           // Final code has been written in test ;

void setSoftwareState() {

  switch(oldSoftState){
    case BOOT:  
          if(prev_Alt > 5){
             pinMode(LED_BUILTIN,HIGH);
             oldSoftState = ACCENT;
          break;
            }
    case ACCENT:
          if(prev_Alt> 650){
            pinMode(LED_BUILTIN,LOW);
            oldSoftState = DEPLOYMENT;
          break;
            } 
          
    case DEPLOYMENT:
          if(prev_Alt < 500) {
            oldSoftState = DESCENT;
          servo_cutting(oldSoftState);
            }         //Sending command to camera subsystem
          //sendCommandtoCamera(SWITCHONCAMERASERVO);      //2 is switch on camera and servo command
          break;
    case DESCENT:
          if(prev_Alt < 5) {
            oldSoftState= END;
          pinMode(buzzer_pin, OUTPUT);
    digitalWrite(buzzer_pin, HIGH);
          break;
            }
    default: break;
  
  }

  prev_Alt = a;
  Serial.println("PREVALT = " + String(prev_Alt));
}














//void setSoftwareState() {
//  if (prev_Alt > 5 && a > prev_Alt && software_state == 1) {
//    software_state = 2;
//  } else if (a > 670 && a < prev_Alt && software_state == 2 || analogRead(ldr_pin) > 400) {
//    software_state = 3;
//  } else if (a < 500 && a < prev_Alt && software_state == 3) {
//    servo_cutting(software_state);
//  } else if (a < 450 && a < prev_Alt && software_state == 3) {
//    servo_cutting(software_state);
//    servo_cutting(software_state);
//    software_state = 4;
//  } else if (a < 5 && a < prev_Alt && software_state == 4) {
//    software_state = 5;
//    //============= SET BUZZER LOGIC HIGH =========================
//    pinMode(buzzer_pin, OUTPUT);
//    digitalWrite(buzzer_pin, HIGH);
//  }
//
//  prev_Alt = a;
//  Serial.println("PREVALT = " + String(prev_Alt));
//}
//
//




void servo_cutting(int soft_state) {
  if (soft_state == 3) {
    myservo.write(180);
    delay(800);
    myservo.write(0);
    delay(800);
  }
}
void writeEEPROM(int deviceaddress, unsigned int eeaddress, byte data )
{
  Wire.beginTransmission(deviceaddress);
  Wire.write((int)(eeaddress >> 8));   // MSB
  Wire.write((int)(eeaddress & 0xFF)); // LSB
  Wire.write(data);
  Wire.endTransmission();

  delay(5);
}
byte readEEPROM(int deviceaddress, unsigned int eeaddress )   //WHY READ EEPROM
{
  byte rdata = 0xFF;

  Wire.beginTransmission(deviceaddress);
  Wire.write((int)(eeaddress >> 8));   // MSB
  Wire.write((int)(eeaddress & 0xFF)); // LSB
  Wire.endTransmission();

  Wire.requestFrom(deviceaddress, 1);

  if (Wire.available()) rdata = Wire.read();

  return rdata;
}

void initBmp(){
  if (!bmp.begin()) {
    #ifdef SER_DEBUG
      Serial.println(F("Could not find a valid BMP280 sensor, check wiring!"));
    #endif

      return;
  }
  /* Default settings from datasheet. */
  bmp.setSampling(Adafruit_BMP280::MODE_NORMAL,     /* Operating Mode. */
                  Adafruit_BMP280::SAMPLING_X2,     /* Temp. oversampling */
                  Adafruit_BMP280::SAMPLING_X16,    /* Pressure oversampling */
                  Adafruit_BMP280::FILTER_OFF,      /* Filtering. */
                  Adafruit_BMP280::STANDBY_MS_500); /* Standby time. */ 

               
}

void setGroundAltitude(){
  double sum = 0;
  for(int i=0; i<2000; i++){
    sum += bmp.readAltitude(1013.25);
  }
  ground_altitude = sum/2000;
}

void setGroundAltitude(float alt){
  ground_altitude = alt;
}

volatile float getBMPAltitute(){
  return (bmp.readAltitude(1013.25) - ground_altitude);
}

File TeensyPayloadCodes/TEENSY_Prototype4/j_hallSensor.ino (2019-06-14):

volatile unsigned long count = 0;

float rpm[3];
int position_i;

void initHall() {
  pinMode(HALLPIN, INPUT);
  count = 0;                        //Initializing count
  attachInterrupt(digitalPinToInterrupt(HALLPIN), raiseCount, CHANGE);  //HENCE increase of 2 when detected
  position_i = 0;
  
  for(int i =0; i<3; i++){
    rpm[i] = 0;
  }
  
}

void raiseCount(){                             
  count++;
}

long giveRPM(volatile unsigned long interruptStartTime){
  volatile unsigned long timeTaken = ((millis() - interruptStartTime))%10000;   //unit is in milliseconds 
  if(timeTaken < 0) {
    timeTaken = 10000 + timeTaken;
  }
  volatile unsigned long noOfRotations = (count/NUMBEROFMAGNETS)/2;    //Detection of "numberOfMagnets" of counts equals 1 rotation in that time
  float instantaneous_rpm = ((float)noOfRotations/(timeTaken))*60*1000;                       //Maths to get RPM

  rpm[position_i] = instantaneous_rpm;
  position_i = (position_i+1)%3;
  
#ifdef SER_DEBUG
  Serial.print("inst RPM = "+String(instantaneous_rpm)+"\t POS = "+String(position_i));
#endif
  
  return findAverageRPM();
  
}

void makeCountZero(){
  count = 0;
}

long findAverageRPM(){
//  Serial.print("========>> IN findAVgRPM");
//  Serial.println(rpm[0]+rpm[1]+rpm[2]);
  return (long)(((rpm[0]+rpm[1]+rpm[2])/3)*3.14/30);  //converting rmp to radians per 
}

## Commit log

2019-05-12 Fixed by updating MPU in smart Delay :) ;)
    [TEENSY_Prototype1.ino, g_gps.ino]
2019-05-12 XBEE Calibration command added with Fixed GPS and MPU, BOOM BOOM :) ;)
    [TEENSY_Prototype1.ino, h_xbee.ino]
2019-05-17 ADDED BMP and MPU callibration interrupt command
2019-05-17 CameraStabilization Beins
2019-05-18 Trying to use PID with camera stabilization code
2019-05-24 Bluetooth Master code for Teensy
2019-05-24 complete PCB Tested code with Bluetooth too
2019-05-25 Added Camera Code
2019-05-27 Making camera software
2019-05-27 Minor changes to camera functioning code
2019-05-27 Thinking of better logic for Camera On, avoiding delay
    [IntegrateCameraAndYaw.ino]
2019-05-27 Stabilize + Bluetooth + Camera ;) ;)
    [IntegrateCameraAndYaw.ino, b_stabilize.ino, pindef.h]
2019-05-28 SD CARD CODE FOR POWER CUTOFF
2019-05-29 Feature for Power loss added
2019-06-14 4 : Complete code with removed SD bugs, 4b:Adding hacks
    [TEENSY_Prototype4.ino, TEENSY_Prototype4b.ino, b_bmp.ino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]
2019-06-20 All other documents added
    [CameraV2.brd, CameraV2.sch, CameraV3.brd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]
2019-06-20 add packets csv from sd and telemetry
    [PACKETS FLIGHT.CSV, Team_3279.csv]

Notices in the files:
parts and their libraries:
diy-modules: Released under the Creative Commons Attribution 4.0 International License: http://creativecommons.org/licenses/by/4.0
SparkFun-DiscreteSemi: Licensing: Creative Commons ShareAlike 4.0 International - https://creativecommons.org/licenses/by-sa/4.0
